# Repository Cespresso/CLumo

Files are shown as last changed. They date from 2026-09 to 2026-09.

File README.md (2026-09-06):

# CLumo

[English] | [日本語 (README.ja.md)](README.ja.md)

CLumo is a palm-sized desk gadget built around an ESP32-C3, an 8x8 LED matrix (MAX7219), and two buttons. It sits on your desk as a tiny companion: a digital pet, a pomodoro timer, a dice roller, or a display you can draw on from your phone.

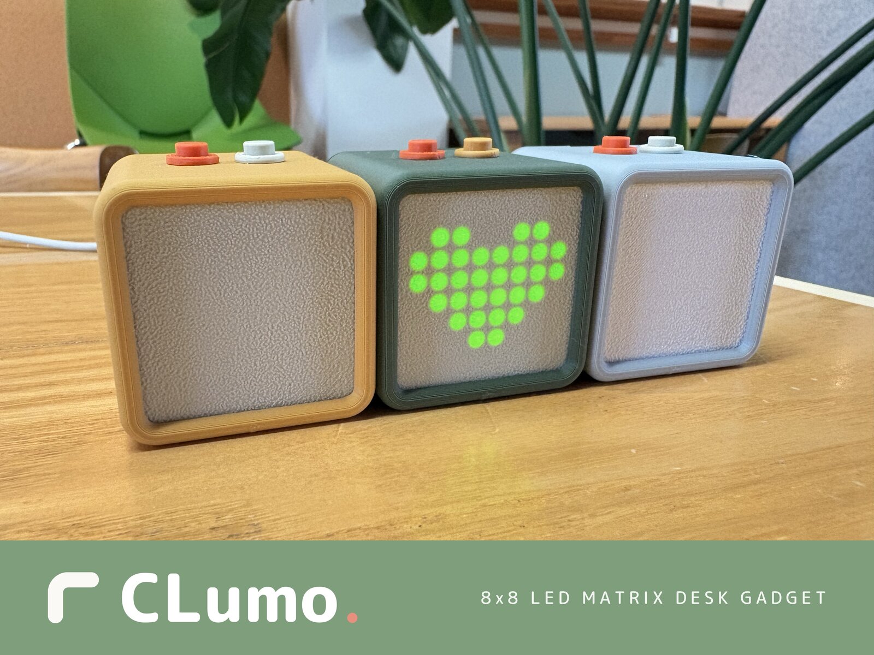
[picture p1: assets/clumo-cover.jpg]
Three CLumo units on a desk in yellow, green, and grey; the green one shows a heart


## Two ways to use it

CLumo ships with two independent firmware variants. Pick one and flash it. You can always switch later.

### 1. Standalone firmware: no app required

Works with just the two buttons; no Bluetooth or phone setup.

- Digital pet: feed it, watch its mood and idle animations
- Pomodoro timer: 25/5 work-break cycles on the LED matrix
- Dice: roll a die with one press

Hold the white button for a second to cycle between modes. The [standalone README](standalone/) lists what each button does in each mode. A running pomodoro and the pet's mood carry across a mode switch, and the mode itself survives a power cycle.

### 2. Companion firmware + Android app

Connects to the CLumo Android app over BLE for richer features.

- Pomodoro: app-configurable work/break cycles shown as a 64-pixel countdown
- Timer: a one-shot countdown from `00:01` to `59:59`, with start, pause, resume, and cancel controls
- My Displays: draw custom 8x8 patterns in the app and send them to the device
- Audio visualizer: the matrix dances to audio streamed from your phone

The [companion README](companion/) covers what the matrix shows before the app connects and what keeps working while the phone is away.

## Quick start

1. Flash the firmware from your browser, no tools to install:
   **https://cespresso.github.io/CLumo/**
   Choose standalone or companion, plug in the device over USB, and click install. Powered by ESP Web Tools; works in Chrome and Edge on desktop, and in Android Chrome via USB-OTG.
2. For the companion firmware, download `clumo.apk` from the [latest GitHub Release](https://github.com/Cespresso/CLumo/releases/latest), install it, and pair with the device using passkey `123456`.

## Repository layout

| Path | Contents |
|---|---|
| [`standalone/`](standalone/) | Standalone firmware (Rust, no BLE): pet / pomodoro / dice |
| [`companion/firmware/`](companion/firmware/) | Companion firmware (Rust + BLE): pomodoro / timer / my displays / visualizer |
| [`companion/android/`](companion/android/) | CLumo Android app (Kotlin, Gradle) |
| [`installer/`](installer/) | Browser-based installer page (ESP Web Tools, served via GitHub Pages) |
| [`hardware/`](hardware/) | Assembly guide, wiring diagram, and 3D-printable enclosure |

## Building from source

Each subproject is self-contained and has its own README with full instructions:

- Firmware ([`standalone/`](standalone/), [`companion/firmware/`](companion/firmware/)): Rust nightly, ESP-IDF v5.2.2, target `riscv32imc-esp-espidf`. Build with `cargo build --release`, flash with `espflash`.
- Android app ([`companion/android/`](companion/android/)): a standard Gradle project. Run `./gradlew assembleDebug` or open it in Android Studio.

## Hardware

- MCU: Seeed XIAO ESP32-C3
- Display: 8x8 LED matrix driven by a MAX7219 (SPI)
- Input: two tactile buttons

The enclosure is five 3D-printed parts. There are no screws or glue: the XIAO snaps into a printed frame, every wire ends in a JST XH connector, and the only soldering is three pin headers. The [assembly guide](hardware/assembly/) walks through the build with photos and includes the parts list and wiring diagram. The 3D model is in [`hardware/models/`](hardware/models/).

## About the AI in this project

CLumo is a one-person project, made with the help of AI tools. The firmware, the Android
app, these READMEs, the installer page, the commit messages and the like were written with
that help: I set the design and the direction, the assistant wrote, and I read it back and
ran it on real CLumo units before every release. The hardware, on the other hand, is
essentially my own hands: designed in a CAD tool, printed, assembled and photographed by me.

## License

[MIT](LICENSE)

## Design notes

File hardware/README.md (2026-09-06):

# Hardware

| Path | Contents |
|---|---|
| [`assembly/`](assembly/) | Step-by-step assembly guide with photos and the wiring diagram ([English](assembly/README.md) / [日本語](assembly/README.ja.md)) |
| [`models/`](models/) | 3D-printable enclosure |

---

| パス | 内容 |
|---|---|
| [`assembly/`](assembly/) | 写真と配線図付きの組み立てガイド（[English](assembly/README.md) / [日本語](assembly/README.ja.md)） |
| [`models/`](models/) | 3D プリント用の外装データ |

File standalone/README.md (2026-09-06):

# CLumo Standalone Firmware

[English] | [日本語 (README.ja.md)](README.ja.md)

Standalone firmware for CLumo. It holds a few simple features that run on nothing but
the two buttons and the LED matrix.

There is no radio, no app, and no pairing: plug in power and everything works with just
the two buttons. Three modes are built in. The current mode is saved to flash, so the
device comes back in the same mode after a power cycle; a running pomodoro and the pet's
mood carry across a mode switch but not across a power cycle.

In the pictures below the left button is orange and the right one is white. Read them as
whatever filament you printed yours with.

## Switching modes

Hold **white** for a second or more. CLumo flashes the icon of the mode it is moving to,
then shows that mode.

| Icon | Mode | What it does |
|:---:|---|---|
| Smiling face | **Pet** | A tiny digital pet that gets hungry over time. Feed it and keep it happy. |
| Hourglass | **Pomodoro** | 25 minutes of work, 5 minutes of break, shown as 64 pixels going out. |
| Five dice pips | **Dice** | Roll a die with one press. |

## Pet

The face is the pet's mood, and the mood follows its hunger: 100 is full, 0 is starving.
It starts at 50 and loses one point every 18 seconds, so an untouched pet goes from
content to sulking in about 3 minutes and to angry in about 12. Feeding adds 20.

| Face | Hunger | Meaning |
|:---:|:---:|---|
| Face with a wide open-mouth smile | 70-100 | Happy. It was fed recently. |
| Face with a small smile | 40-69 | Content. This is where it starts. |
| Face with a downturned mouth | 10-39 | Sad. It wants to be fed. |
| Face with a furrowed brow and downturned mouth | 0-9 | Angry. Feed it now. |

Between moods the pet is never quite still:

| Face | When you see it |
|:---:|---|
| Face with eyes closed | A blink. Happy, content and sad pets blink every couple of seconds; an angry pet just glares. |
| Face with eyes shifted left Face with eyes shifted right | Looking around. Every 5 to 15 seconds it glances left, then right. |

Orange feeds it: hunger goes up by 20 and the pet beams for a moment. White pokes it, and
it scowls for a moment before settling back into its mood.

## Pomodoro

The matrix is the timer. Every phase starts with all 64 pixels lit and they go out one by
one, from the top-left toward the bottom-right, so the lit block shrinking toward the
bottom-right corner is time running out.

| Screen | What it means |
|:---:|---|
| Hourglass | Idle. Nothing is counting. Press orange to start 25 minutes of work. |
| Lower part of the matrix lit | About a third of the way through a phase. Work and break look the same. |
| Bottom rows of the matrix lit | About two thirds of the way through. |
| Every pixel lit | A phase has ended. The whole matrix flashes three times, then the next phase starts on its own: a 5-minute break after work, 25 minutes of work after a break. |

Orange starts the timer when it is idle, pauses it when it is counting, and resumes it
when it is paused; a pause freezes the picture where it is. White resets to idle from any
state.

Both buttons are ignored while the matrix is flashing. Switching to another mode does not
stop the timer: it keeps counting, and you find it where it got to when you come back.

## Dice

The matrix rests on the last roll; a freshly started CLumo shows a five. Press orange and
faces flip past for about a second and a half, slowing down before they land on the result.

| 1 | 2 | 3 | 4 | 5 | 6 |
|:---:|:---:|:---:|:---:|:---:|:---:|
| One pip | Two pips | Three pips | Four pips | Five pips | Six pips |

Orange rolls, and a press while a roll is still spinning is ignored. White has no effect
in this mode.

## Buttons at a glance

| | Orange | White |
|---|---|---|
| **Any mode** | | Hold for a second: next mode |
| **Pet** | Feed | Poke |
| **Pomodoro** | Start / pause / resume | Reset to idle |
| **Dice** | Roll | |

## Build & flash

### Requirements

- Rust nightly with the `rust-src` component. If you use rustup,
  `rust-toolchain.toml` installs it automatically.
- `ldproxy` and `espflash`:

  ```bash
  cargo install ldproxy espflash
  ```

- Python 3.10 or newer
- ESP-IDF v5.2.2

### Flash

Connect the board over USB-C and run:

```bash
cargo run
```

This builds the firmware, flashes it with `espflash`, and opens the serial
monitor.

## Appendix: pin assignments

The board is a Seeed Studio XIAO ESP32C3 and the matrix is a MAX7219.

| GPIO | Connected to | Direction |
|:---:|---|---|
| 8 | Matrix SCLK | Output (SPI) |
| 9 | Matrix CS | Output (SPI) |
| 10 | Matrix MOSI | Output (SPI) |
| 3 | Orange button | Input, internal pull-up (low when pressed) |
| 4 | White button | Input, internal pull-up (low when pressed) |

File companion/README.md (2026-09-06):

# CLumo Companion

[English] | [日本語 (README.ja.md)](README.ja.md)

The firmware and app for using CLumo together with the CLumo Android app. The
device's four functions map one to one onto the app's four functions, and
switching between them, as well as setting durations, happens in the app.

| Directory | Contents |
|---|---|
| [`firmware/`](firmware/) | BLE firmware. The BLE protocol specification lives here too |
| [`android/`](android/) | The CLumo Android app |

Most of what you need to know is already in the app's help pages. This README
therefore concentrates on what the device shows before the app connects, and on
what it does while the phone is away.

In the pictures below the left button is orange and the right one is white. Read
them as whatever filament you printed yours with.

## Getting started

1. Open the [installer page](https://cespresso.github.io/CLumo/), choose the companion firmware, connect the device over USB, and flash.
2. Download `clumo.apk` from the [latest release](https://github.com/Cespresso/CLumo/releases/latest) and install it on a phone running Android 8.0 or newer.
3. Power the device and put it near the phone.
4. Open the app, tap "Find CLumo", and tap the CLumo it finds. Enter passkey `123456` when asked.

From then on, opening the app reconnects on its own.

## When you power it on

The device first shows its connection state, and switches to a function's screen
once the app is connected and ready.

| Screen | What it means |
|:---:|---|
| Thick corner in the top-left | Never paired. A freshly flashed device waits on this screen. Press orange or white and it goes straight to Pomodoro or Timer, usable on its own. |
| Thick corner in the top-left with a dot in the bottom-right | Paired but not connected. Shown for about a second after power-on and right after a disconnect, then the device returns to the function it was last using. |
| The corner-and-dot screen alternating with every pixel off | Connecting. Blinks from the moment the phone connects until the app has finished reading the device's state. |

## The four functions

Switching functions is a matter of picking one in the app. The device's buttons
never change it. The device remembers the last function and comes back to it
after a power cycle. Brightness is a slider in the app, and the device remembers
that too.

| Screen | Function | What it does |
|:---:|---|---|
| Hourglass | **Pomodoro** | Alternates work and break. The durations are set in the app and start out at 25 and 5 minutes. |
| Clock face | **Timer** | A one-shot countdown from 00:01 to 59:59. When time is up it blinks until you do something. |
| Heart | **My Displays** | Shows an 8x8 picture drawn in the app. A heart, a smile, and a star come preloaded. |
| Eight bars of different heights | **Visualizer** | Eight bars move with the audio playing on the phone. Sensitivity is adjusted in the app. |

Pomodoro and Timer show their icon while idle. Once started, the remaining time is
64 pixels: they start fully lit and go out from the top-left toward the
bottom-right.

| Screen | What it means |
|:---:|---|
| Lower part of the matrix lit | About a third of the way through. Work, break, and timer all look the same. A pause freezes the picture where it is. |
| Every pixel lit | The end-of-phase flash. Pomodoro flashes three times and moves to the next phase on its own; Timer keeps blinking until you do something. |

## While the phone is away

Losing the connection does not stop the device. The connection screen shows for
about a second, then the function's screen comes back.

| Function | What the device does on its own |
|---|---|
| **Pomodoro** | Keeps counting. Orange starts, pauses and resumes. White resets. |
| **Timer** | Keeps counting. Orange starts, pauses and resumes, and after completion starts the same duration again. White cancels. |
| **My Displays** | Keeps the last picture sent, even through a power cycle. Switching pictures goes through the app, so the buttons do nothing while it is away. |
| **Visualizer** | The bars fall and go dark once audio stops arriving. The buttons do nothing. |

While connected, orange and white step to the next and previous picture in My
Displays, and raise and lower the sensitivity in Visualizer.

## Permissions

| Permission | When it is asked | What it is for |
|---|---|---|
| Nearby devices (Bluetooth) | On first launch | Finding and connecting to CLumo |
| Microphone | The first time you start the visualizer | Picking up the audio being played |
| Notifications (Android 13 and newer) | The first time you start the visualizer | The notification of the service that keeps the connection |

## Widgets

Two home-screen widgets are included. Both act on the "main CLumo", the one
starred in the device list.

| Widget | Size | What it does |
|---|:---:|---|
| **CLumo controls** | 4x1 | Start, pause, reset and cancel for Pomodoro and Timer. Reconnects when the device is not connected. |
| **CLumo** | 2x2 | Mirrors the device's face. Tapping it opens the app. |

## If something goes wrong

| Symptom | Cause | Fix |
|---|---|---|
| "Find CLumo" finds nothing | The device runs the standalone firmware, which has no Bluetooth | Flash the companion firmware from the installer |
| "This CLumo firmware is not supported" | The companion firmware is out of date | Flash the latest companion firmware from the installer |
| "Connection lost", over and over, on a device that used to work | The device was reflashed and lost its side of the pairing | Forget CLumo in Android's Bluetooth settings, then connect again |

A reflashed device introduces itself as a new one, but the app recognises it as the
same CLumo, so its name, colors, and main-device setting carry over. Enter the passkey
within 30 seconds; after that the device gives up on the pairing and you start over. A device you no longer use
can be removed from the list: hold its card to start tidying and each card's right edge
becomes a remove button. "Remove this device" in the device screen's menu does the same.
The app cannot remove the Android pairing, so forget it in Bluetooth settings separately.
A device removed by mistake comes back through "Find CLumo" with nothing to re-enter.

For anything else, follow the app's dialogs.

## For developers

- BLE protocol specification and firmware build: [`firmware/README.md`](firmware/README.md)
- App build: [`android/README.md`](android/README.md)

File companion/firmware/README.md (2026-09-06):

# CLumo Companion Firmware

Firmware for CLumo, an ESP32-C3 desk gadget with an 8x8 LED matrix (MAX7219)
and two physical buttons. It pairs with the CLumo Android companion app over
BLE; the device's four modes map 1:1 to the app's functions.

This document is the source of truth for the BLE protocol (v3). What the device
shows before the app connects, and what it does while the phone is away, is in
the [companion README](../README.md).

## Modes

| Value | Mode | Description | Buttons |
|---|---|---|---|
| 0 | Pomodoro | Work/break countdown with app-settable durations. The matrix is a 64-pixel progress bar; idle shows an hourglass. | Main: start/pause/resume. Sub: reset. |
| 1 | Timer | One-shot countdown configurable from `00:01` to `59:59`. Idle shows a clock face. At `00:00`, the matrix blinks every 400 ms until operated. | Main: start/pause/resume/restart. Sub: cancel. |
| 2 | Display | Shows the 8-byte bitmap last committed over DISPLAY_FRAME, with DISPLAY_PREVIEW frames drawn on top until they expire. Persisted in NVS across reboots; blank until the first commit arrives. | Reported over BUTTON; the app cycles its saved patterns. |
| 3 | Visualizer | Bar visualizer driven by column heights streamed to the VISUALIZER characteristic. The matrix stays blank until data arrives; bars rise instantly, fall smoothly, and decay to zero when data stops. | Reported over BUTTON; the app steps visualizer sensitivity. |

Modes are selected by the Android companion app through the MODE characteristic;
buttons never change the mode. A mode change immediately shows the selected
mode's normal frame without an icon splash. The current mode is persisted in NVS
and restored on boot. Firmware upgrading from protocol v1 migrates the old
Display value `1` to `2` and Visualizer value `2` to `3`, deriving the result
into the `MODE2` key and leaving the pre-v2 `MODE` and `MODE_SCHEMA` keys
read-only forever. Each NVS setter commits on its own, so migrating in place
across two keys could be interrupted between them; because `1` maps to `2` and
`2` maps to `3`, re-running the migration on its own output would silently turn
Display into Visualizer. Deriving into a separate key makes the migration
idempotent: an interrupted boot recomputes the same value from the same
untouched inputs. Every accepted mode change is pushed to subscribers of the
MODE characteristic.

Buttons register on release after 50 ms of debounce; there is no long press. In
Pomodoro and Timer the firmware acts on the press itself, so those modes stay
usable while disconnected. In Display and Visualizer the firmware only notifies
BUTTON, so those presses do nothing while disconnected.

All mode handlers live for the process lifetime. Pomodoro and Timer continue
counting while another mode is visible and resume from the same state when selected
again. Pomodoro work/break durations, Timer configured duration, brightness, Display
bitmap, and current mode are persisted in NVS. Countdown execution state is not
persisted across reboot; both countdowns boot idle with their stored durations.

While disconnected, the matrix briefly shows the link-loss icon and then returns
to the current mode's standalone frame. A device that has never bonded keeps the
icon up instead, until a phone pairs or a Pomodoro/Timer button press puts it to
standalone use; a device with nothing to reconnect to should not look like it is
running something. The connection icon keeps blinking until a connected client
finishes its encrypted GATT initial sync.

## Build & flash

Requirements:

- Rust **nightly** with the `rust-src` component (see `rust-toolchain.toml`)
- ESP-IDF **v5.2.2** (fetched automatically by `esp-idf-sys`; requires Python >= 3.10)
- Target `riscv32imc-esp-espidf`, linker `ldproxy`, flasher `espflash`

```bash
# Install tooling once
cargo install ldproxy espflash

# Build, flash, and monitor
cargo run
```

## Testing

`lib.rs` exposes the mode-agnostic modules (`countdown`, `display_routing`,
`display_state`, `mode_values`, `settings_values`, `visualizer_values`) so
they can be unit tested on the host, without ESP-IDF. `--target` must override the
crate's default ESP32 target:

```bash
cargo test --lib --target <host-triple>   # e.g. aarch64-apple-darwin, x86_64-unknown-linux-gnu
```

CI runs this on every push and PR (`firmware-ci.yml`). `handlers/`, `mode.rs`, and
`main.rs` depend on ESP-IDF and are not covered by host tests.

## Pairing

- Security: BLE bonding with MITM protection, passkey **123456** (DisplayOnly).
- All readable and writable characteristics require an encrypted (paired) connection.
  BUTTON is notify-only, and NimBLE's auto-generated CCCD is subscribable without
  encryption, so the firmware instead withholds button notifications until a client
  has completed the encrypted initial sync.
- A connected client blocks advertising, so a client that connects but never
  completes that encrypted initial sync (bonds but never reads DEVICE_ID, or isn't
  CLumo's app at all) is force-disconnected after 60s, so a real client isn't
  locked out until power-cycle.

## BLE protocol v3

### State ownership

CLumo (the device) is the sole source of truth for everything it runs or persists;
the app reads and reflects that state rather than assuming it, and reconciles from
a fresh read on every reconnect. Everything the app owns locally never reaches the
device at all. Nothing is owned by both sides: where two representations of the
same fact exist (Display's live preview vs. its committed frame), one is always an
explicit, expiring projection of the other, never an independent second source
(see "Commit, preview and streams" below).

| State | Owner | On reconnect |
|---|---|---|
| Mode | Device (NVS `STATE`) | App re-reads MODE and adopts it as observed; an unexpired (<3s) pending tap is re-sent, not discarded, until the device confirms it |
| Brightness | Device (NVS `STATE`) | Same as Mode |
| Pomodoro/Timer: running state, phase, remaining time | Device only; not persisted, resets to idle on reboot | App re-reads POMODORO/TIMER |
| Pomodoro durations, Timer configured duration | Device (NVS, one namespace per handler) | App re-reads POMODORO/TIMER |
| Display: which 8-byte frame is on the matrix | Device (NVS `DISPLAY`, committed frame only; a live preview is never persisted) | App subscribes to DISPLAY_FRAME and re-reads it; the value is the committed frame, never a live preview |
| Display: pattern names and the app's saved-pattern library | App only; the device has no concept of a pattern, only bytes | Not applicable; the app matches its library against the frame it reads by content |
| Visualizer sensitivity, automatic low-volume boost | App only; a local audio-processing parameter, never sent to the device | Not applicable |
| Device alias, appearance (colors) | App only; cosmetic and local | Not applicable |
| Primary device selection | App only; local | Not applicable |
| Device identity (UUID) | Device (NVS `DEVICE`, generated once on first boot, read-only) | App re-reads DEVICE_ID |

Rule of thumb: if losing power should not lose it, the device owns it and persists
it; if it is purely how the app presents the device (a name, a color, a saved
pattern's name), the app owns it and never sends it.

### Service

| Item | Value |
|---|---|
| Service UUID | `455aa9f0-2999-43de-81b4-54e0de255927` |
| Advertising name | `CLumo-XXXX` where `XXXX` is the uppercase hex of device ID bytes 0 and 1 |

### Characteristics

| Name | UUID | Properties | Payload |
|---|---|---|---|
| MODE | `681285a6-247f-48c6-80ad-68c3dce18586` | READ, WRITE, NOTIFY | 1 byte: mode `0..=3`. Write switches mode; a same-value write is a no-op. Firmware notifies after an accepted mode change. Invalid values are ignored. |
| DISPLAY_PREVIEW | `681285a6-247f-48c6-80ad-68c3dce1858d` | WRITE_NR | 8 bytes: a row bitmap shown at once and never persisted. Ignored outside Display mode. |
| DISPLAY_FRAME | `681285a6-247f-48c6-80ad-68c3dce1858c` | READ, WRITE, NOTIFY | 8 bytes: the committed row bitmap. Write commits in any mode (see below). READ returns the committed frame, never a live preview. Notifies on every commit. |
| VISUALIZER | `681285a6-247f-48c6-80ad-68c3dce1858e` | WRITE_NR | 8 bytes: column heights `0..=8`. Ignored outside Visualizer mode. |
| POMODORO | `681285a6-247f-48c6-80ad-68c3dce18587` | READ, WRITE, NOTIFY | Write: command (below). Read/notify: 6-byte status (below). |
| TIMER | `681285a6-247f-48c6-80ad-68c3dce1858a` | READ, WRITE, NOTIFY | Write: command (below). Read/notify: 5-byte status (below). |
| BRIGHTNESS | `681285a6-247f-48c6-80ad-68c3dce18588` | READ, WRITE, NOTIFY | 1 byte: MAX7219 intensity, clamped to `0..=15`. Firmware echoes the applied value via notify. |
| DEVICE_ID | `681285a6-247f-48c6-80ad-68c3dce18589` | READ | 16 bytes: stable UUIDv4 device identifier, generated on first boot and persisted in NVS. |
| BUTTON | `681285a6-247f-48c6-80ad-68c3dce1858b` | NOTIFY | 2 bytes `[mode, button]`: a button press in a mode the firmware does not handle itself (see below). |

Characteristics are created in the table's order, and ATT handles follow creation
order. The v2 `DISPLAY` characteristic (`…8585`) is gone, and DISPLAY_FRAME's notify
adds a CCCD, so every handle after MODE differs from v2. A client that rediscovers
services finds `…8585` missing and rejects the device (the Android app refreshes its
GATT cache once when a required characteristic is missing, then gives up); a v3 app
does the same on v2 firmware. A bonded client that trusts a stale cache instead
writes at the handles it remembers. Its DISPLAY value handle is now DISPLAY_PREVIEW's
value: volatile, ignored outside Display mode, never persisted. Its POMODORO command
handle is now DISPLAY_FRAME's value, where every v2 command is shorter than 8 bytes
and is rejected with `0x0D` instead of committed. And its TIMER read lands on
VISUALIZER's value, which cannot be read, so its initial sync never completes and it
never streams. Either way no v2 display data can reach NVS, which is the failure v3
exists to remove.

**Add new characteristics at the end of the service, never in the middle.** NimBLE
assigns ATT handles in creation order, so inserting a characteristic ahead of an
existing one shifts that one's handle. A client that already bonded reconnects from
its cached GATT database and keeps using the old handles, so it silently reads the
wrong attribute. This is what broke reconnection entirely when BUTTON was first
added ahead of DEVICE_ID. Appending leaves every existing handle untouched, so clients
upgrading from older firmware keep working; they just do not see the new
characteristic until their cache is refreshed. The companion app forces exactly one
refresh when a characteristic it requires or knows as optional is missing from its
cache, which is how the new features come alive after a firmware upgrade without
re-pairing. v3 broke this rule once, on purpose: the three display characteristics
were placed together after MODE, with the preview stream first so that a v2 client
keeping its cached handles writes its frames into a volatile stream and its short
commands into a characteristic that rejects them, instead of committing into
DISPLAY_FRAME. Three characteristics replace one, so every handle from DISPLAY_FRAME
on was moving regardless. From v3 on, the rule holds again.

### Frame payloads

- **DISPLAY_FRAME and DISPLAY_PREVIEW**: row bitmap. Byte 0 = top row, byte 7 = bottom
  row. Within a byte, bit 7 (MSB) = leftmost column, bit 0 = rightmost column.
- **VISUALIZER**: column heights. Byte 0 = leftmost column, byte 7 = rightmost column.
  Each byte is a height `0..=8` (values above 8 are clamped).

A DISPLAY_FRAME write shorter than 8 bytes is rejected with ATT error `0x0D` (invalid
attribute value length), so the readable committed frame is never replaced by a short
payload. It is also what keeps a stale v2 client's POMODORO commands, which land on
this handle, out of NVS. Short writes to the two streams are logged and dropped; they
have no readable value and write-without-response carries no error. Longer writes are
accepted and only the first 8 bytes are used.

### Commit, preview and streams

A write to DISPLAY_FRAME is a commit: the frame becomes the committed frame in any
mode, is written to NVS when it differs from the previous one, replaces any pending
preview, and is pushed to DISPLAY_FRAME subscribers whether or not it changed, so a
client's pending write is always answered. Display repaints on its next tick if it
is already on the matrix, and shows the frame on entry otherwise. A commit whose NVS
write fails is still notified as accepted: the frame is committed in memory and
shown, and the failure surfaces only as the previous frame returning after a reboot,
with a warning in the firmware log.

A write to DISPLAY_PREVIEW is shown at once while Display is on the matrix and is
never persisted. It expires 5 seconds after the last preview, on a mode change, and
on disconnect, each time restoring the committed frame. Clients keep an edit alive by
re-sending it inside that window.

A write to VISUALIZER moves the bars while Visualizer is on the matrix and is
otherwise dropped.

Nothing rides on MODE besides the mode: there is no announce handshake and no
same-value commit. Of the three display characteristics, only DISPLAY_FRAME
reaches NVS.

### BUTTON notify payload (2 bytes)

| Index | Field | Values |
|---|---|---|
| 0 | `mode` | mode the press happened in: `2` = Display, `3` = Visualizer |
| 1 | `button` | 0 = main, 1 = sub |

Emitted only in Display and Visualizer mode. Pomodoro and Timer presses are
consumed by the firmware and never notified. The firmware holds no state for
these presses: it notifies only after a client has completed the encrypted
initial sync, and a press outside that window is simply lost rather than queued.

Companion apps are expected to treat main as "next / increase" and sub as
"previous / decrease" for whatever that mode presents.

### POMODORO commands (writes)

| Bytes | Command |
|---|---|
| `[0x01]` | Start (from idle) or resume (from paused). No-op while running. |
| `[0x02]` | Pause. No-op unless running. |
| `[0x03]` | Reset: state = idle, phase = work, remaining = work duration. |
| `[0x10, work_min, break_min]` | Set durations in minutes. Both values are clamped to `1..=99` and persisted in NVS. Applied immediately when idle; otherwise the new values take effect from the next reset or phase change. |

Every accepted command results in a status notify, including no-ops as a status
echo. Pomodoro keeps running in the background while another mode is shown, so
Reset is accepted from any mode; Start, Pause, and Set durations are processed
only while the device is in Pomodoro mode (ignored, with a status echo,
otherwise).

### POMODORO status (read value and notify payload, 6 bytes)

| Index | Field | Values |
|---|---|---|
| 0 | `state` | 0 = idle, 1 = running, 2 = paused |
| 1 | `phase` | 0 = work, 1 = break |
| 2..3  | `remaining` | remaining seconds of the current phase, big-endian u16 |
| 4 | `work_min`  | work duration in minutes |
| 5 | `break_min` | break duration in minutes |

The firmware notifies on state or phase changes, once per second while running,
and after every accepted command. When a phase completes, it plays a short
full-screen blink, switches phase, and keeps running.

### TIMER commands (writes)

| Bytes | Command |
|---|---|
| `[0x01]` | Start from idle, resume from paused, or restart the configured duration after completion. No-op while running. |
| `[0x02]` | Pause. No-op unless running. |
| `[0x03]` | Cancel: state = idle and remaining = configured duration. The configured duration is retained. |
| `[0x10, minutes, seconds]` | Set duration while idle. Minutes and seconds must each be `0..=59`, and `00:00` is rejected. While running, paused, or completed, the setting is left unchanged and the current status is echoed. Accepted values are persisted in NVS. |

Every accepted command results in a status notify, including no-ops as a status
echo. The timer keeps running in the background while another mode is shown, so
Cancel is accepted from any mode; Start, Pause, and Set duration are processed
only while the device is in Timer mode (ignored, with a status echo,
otherwise).

### TIMER status (read value and notify payload, 5 bytes)

| Index | Field | Values |
|---|---|---|
| 0 | `state` | 0 = idle, 1 = running, 2 = paused, 3 = completed |
| 1..2  | `remaining` | remaining seconds, big-endian u16 |
| 3 | `minutes` | configured minutes (`0..=59`) |
| 4 | `seconds` | configured seconds (`0..=59`) |

The firmware notifies on state changes, once per second while running, and after
every accepted command. At completion, remaining is `0` and the matrix blinks
on/off every 400 ms until Start/Cancel is received or either button is pressed.

### Countdown LED render rule

Pomodoro and Timer use a 64-pixel countdown progress bar. Companion apps that
mirror the device display must use exactly:

```
lit = ceil(remaining_secs * 64 / total_secs)   // clamped to 0..=64
```

For Pomodoro, `total_secs` is the current phase duration. For Timer, it is the
configured duration. Pixels are indexed row-major from the top-left
(`index = row * 8 + column`, bit 7 = leftmost column); the last `lit` pixel
indices are ON. As time passes, pixels turn off from the top-left toward the
bottom-right. A paused frame remains static.

Idle (state `0`) does not draw the bar. It shows the mode's icon, as row bitmaps
in the DISPLAY_FRAME byte order:

| Mode | Icon | Rows |
|---|---|---|
| Pomodoro | hourglass | `7E 42 24 18 18 24 42 7E` |
| Timer | clock face | `3C 52 91 9D 81 81 42 3C` |

A running or paused countdown with all 64 pixels lit is therefore distinguishable
from idle by the status byte alone, which is what the app's mirror keys on.

## Appendix: pin assignments

The board is a Seeed Studio XIAO ESP32C3 and the matrix is a MAX7219.

| GPIO | Connected to | Direction |
|:---:|---|---|
| 8 | Matrix SCLK | Output (SPI) |
| 9 | Matrix CS | Output (SPI) |
| 10 | Matrix MOSI | Output (SPI) |
| 3 | Main button | Input, internal pull-up (low when pressed) |
| 4 | Sub button | Input, internal pull-up (low when pressed) |

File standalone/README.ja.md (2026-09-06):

# CLumo 単独版ファームウェア

[English (README.md)](README.md) | [日本語]

CLumo の単独版ファームウェアです。ボタン二つとマトリクスLEDだけで機能する簡単な機能が含まれています。

無線もアプリもペアリングもありません。電源をつなげば、ボタン 2 つだけで全部動きます。
モードは 3 つ。現在のモードはフラッシュに保存されるので、電源を入れ直しても同じモードで
立ち上がります。動作中のポモドーロとペットの機嫌はモードを切り替えても続きますが、
電源を切ると消えます。

以下で用いる実機の図は、左が橙ボタン、右が白ボタンにしてますが、適宜利用したフィラメントに応じて読み替えてください。

## モードの切り替え

**白**を 1 秒以上長押しします。移る先のモードのアイコンが一瞬出て、そのモードの画面になります。

| アイコン | モード | できること |
|:---:|---|---|
| にこにこした顔 | **ペット** | 時間とともに腹が減る小さなデジタルペット。餌をやってご機嫌を保ちます。 |
| 砂時計 | **ポモドーロ** | 作業 25 分・休憩 5 分。64 個のドットが消えていくことで残り時間を示します。 |
| サイコロの 5 | **サイコロ** | ボタンひと押しでサイコロを振ります。 |

## ペット

顔がペットの機嫌で、機嫌は空腹度で決まります。100 が満腹、0 が飢え。
50 から始まり、18 秒ごとに 1 減ります。放っておくと 3 分ほどで不機嫌に、12 分ほどで怒ります。
餌をやると 20 増えます。

| 顔 | 空腹度 | 意味 |
|:---:|:---:|---|
| 口を大きく開けて笑う顔 | 70〜100 | ご機嫌。餌をもらったばかり。 |
| 小さく笑う顔 | 40〜69 | 平常。最初はここから。 |
| 口がへの字の顔 | 10〜39 | 不機嫌。餌をほしがっている。 |
| 眉をひそめて口がへの字の顔 | 0〜9 | 怒っている。すぐ餌をやりましょう。 |

機嫌とは別に、ペットはじっとしていません。

| 顔 | いつ出るか |
|:---:|---|
| 目を閉じた顔 | まばたき。ご機嫌・平常・不機嫌のときは数秒おきにまばたきします。怒っているときはにらんだままです。 |
| 目が左に寄った顔 目が右に寄った顔 | よそ見。5〜15 秒おきに左、右と目をやります。 |

橙で餌をやると空腹度が 20 増え、ペットが一瞬にっこりします。白でつつくと一瞬むっとして、
元の機嫌に戻ります。

## ポモドーロ

マトリクスそのものがタイマーです。どのフェーズも 64 個全部が点いた状態から始まり、
左上から右下へ向かって 1 つずつ消えていきます。点いている塊が右下の角へ縮んでいくのが、
残り時間です。

| 画面 | 意味 |
|:---:|---|
| 砂時計 | 待機中。何も動いていません。橙を押すと 25 分の作業が始まります。 |
| マトリクスの下側が点灯 | フェーズの 3 分の 1 ほどが過ぎたところ。作業も休憩も同じ見え方です。 |
| マトリクスの下 2 段強が点灯 | 3 分の 2 ほどが過ぎたところ。 |
| 全ドット点灯 | フェーズ終了。全体が 3 回点滅し、次のフェーズが自動で始まります。作業のあとは 5 分の休憩、休憩のあとは 25 分の作業です。 |

橙は待機中なら開始、カウント中なら一時停止、停止中なら再開です。一時停止すると絵はその場で
止まります。白はどの状態からでも待機中に戻します。

点滅している間はどちらのボタンも受け付けません。他のモードに切り替えてもタイマーは止まりません。
戻ってくると、進んだところから続いています。

## サイコロ

マトリクスには最後に出た目が残ります。起動直後は 5 です。橙を押すと 1.5 秒ほど目がめくれ、
だんだん遅くなって結果に止まります。

| 1 | 2 | 3 | 4 | 5 | 6 |
|:---:|:---:|:---:|:---:|:---:|:---:|
| サイコロの 1 の目 | サイコロの 2 の目 | サイコロの 3 の目 | サイコロの 4 の目 | サイコロの 5 の目 | サイコロの 6 の目 |

橙で振ります。回転中に押しても受け付けません。白はこのモードでは何もしません。

## ボタン早見表

| | 橙 | 白 |
|---|---|---|
| **全モード共通** | | 1 秒長押し: 次のモードへ |
| **ペット** | 餌をやる | つつく |
| **ポモドーロ** | 開始 / 一時停止 / 再開 | 待機中に戻す |
| **サイコロ** | 振る | |

## ビルドと書き込み

### 必要なもの

- `rust-src` コンポーネント付きの Rust nightly。rustup を使っていれば
  `rust-toolchain.toml` が自動で入れます。
- `ldproxy` と `espflash`:

  ```bash
  cargo install ldproxy espflash
  ```

- Python 3.10 以上
- ESP-IDF v5.2.2

### 書き込み

ボードを USB-C でつないで:

```bash
cargo run
```

ビルドして `espflash` で書き込み、シリアルモニタを開きます。

## 付録: ピン配置

ボードは Seeed Studio XIAO ESP32C3、LED マトリクスは MAX7219 です。

| GPIO | つながる先 | 向き |
|:---:|---|---|
| 8 | マトリクス SCLK | 出力（SPI） |
| 9 | マトリクス CS | 出力（SPI） |
| 10 | マトリクス MOSI | 出力（SPI） |
| 3 | 橙ボタン | 入力、内部プルアップ（押すと Low） |
| 4 | 白ボタン | 入力、内部プルアップ（押すと Low） |

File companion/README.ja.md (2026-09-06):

# CLumo アプリ協調版

[English (README.md)](README.md) | [日本語]

CLumo を Android アプリ「CLumo」と組み合わせて使うための、ファームウェアとアプリのセットです。
本体の 4 つの機能はアプリの 4 つの機能と一対一で対応していて、機能の切り替えや時間の設定はアプリから行います。

| ディレクトリ | 内容 |
|---|---|
| [`firmware/`](firmware/) | BLE 対応ファームウェア。BLE プロトコルの仕様もここにあります |
| [`android/`](android/) | Android アプリ「CLumo」 |

使い方の説明の多くは、アプリの中のヘルプにある程度書いてあります。
そのため、この README では、アプリが開く前の本体の表示と、スマホが手元にないときの本体の動きを中心にまとめています。

以下で用いる実機の図は、左が橙ボタン、右が白ボタンにしてますが、適宜利用したフィラメントに応じて読み替えてください。

## はじめる

1. [インストーラページ](https://cespresso.github.io/CLumo/)で「アプリ協調版」を選び、本体を USB でつないで書き込みます。
2. [最新の Release](https://github.com/Cespresso/CLumo/releases/latest) から `clumo.apk` をダウンロードして、Android 8.0 以上のスマホにインストールします。
3. 本体の電源を入れて、スマホの近くに置きます。
4. アプリを開いて「CLumo を探す」を押し、見つかった CLumo をタップします。求められたらパスキー `123456` を入力します。

次からは、アプリを開くだけで自動的に再接続します。

## 電源を入れると

本体はまず接続の状態を表示し、アプリがつながって準備を終えると、それぞれの機能の画面に
切り替わります。

| 画面 | 意味 |
|:---:|---|
| 左上に太い角 | まだ一度もペアリングしていません。書き込み直後の本体はこの画面のまま待ちます。橙か白を押せば、その場でポモドーロやタイマーを本体だけで使えます。 |
| 左上に太い角、右下に点 | ペアリング済みですが、つながっていません。起動直後と切断された直後に 1 秒ほど表示され、そのあと最後に使っていた機能の画面に戻ります。 |
| 角と点の画面と、全ドット消灯の画面が交互に | 接続中。スマホがつながってから、アプリが本体の状態を読み終えるまで点滅します。 |

## 4 つの機能

機能の切り替えはアプリで選ぶだけで、本体のボタンでは変わりません。本体は最後に選んだ機能を
覚えていて、電源を入れ直してもその機能で立ち上がります。明るさもアプリのスライダーで変え、
本体が覚えます。

| 画面 | 機能 | できること |
|:---:|---|---|
| 砂時計 | **ポモドーロ** | 作業と休憩を交互に繰り返します。分数はアプリで設定でき、最初は作業 25 分・休憩 5 分です。 |
| 時計の文字盤 | **タイマー** | 00:01 から 59:59 までの一回きりのカウントダウン。時間が来ると操作されるまで点滅します。 |
| ハート | **マイ表示** | アプリで描いた 8×8 の絵を本体に表示します。最初からハート・スマイル・ほしが入っています。 |
| 高さの違う 8 本のバー | **ビジュアライザ** | スマホで再生中の音に合わせて 8 本のバーが動きます。感度はアプリで調整します。 |

ポモドーロとタイマーは、待機中は上のアイコンを出し、始めると残り時間を 64 個のドットで
示します。全部点いた状態から始まり、左上から右下へ向かって消えていきます。

| 画面 | 意味 |
|:---:|---|
| マトリクスの下側が点灯 | 3 分の 1 ほど過ぎたところ。作業、休憩、タイマーのどれも同じ見え方です。一時停止すると絵はその場で止まります。 |
| 全ドット点灯 | 終了の点滅。ポモドーロは 3 回点滅して次のフェーズへ自動で進み、タイマーは操作されるまで点滅し続けます。 |

## スマホが離れているとき

接続が切れても本体は止まりません。切れた直後に接続の画面が 1 秒ほど出て、そのあと機能の
画面に戻ります。

| 機能 | 本体だけでできること |
|---|---|
| **ポモドーロ** | 動き続けます。橙で開始・一時停止・再開、白でリセット。 |
| **タイマー** | 動き続けます。橙で開始・一時停止・再開、終了後の橙は同じ時間でもう一度。白でキャンセル。 |
| **マイ表示** | 最後に送った絵がそのまま残り、電源を切っても消えません。絵の切り替えはアプリを通すので、離れている間はボタンを押しても何も起きません。 |
| **ビジュアライザ** | 音が届かなくなるとバーが下がって消えます。ボタンは何もしません。 |

つながっているときは、マイ表示では橙で次の絵、白で前の絵に切り替わり、ビジュアライザでは
橙で感度が上がり、白で下がります。

## 権限

| 権限 | 尋ねるとき | 使いみち |
|---|---|---|
| 付近のデバイス（Bluetooth） | 初回起動時 | CLumo を探して接続する |
| マイク | ビジュアライザを初めて開始するとき | 再生中の音を拾う |
| 通知（Android 13 以上） | ビジュアライザを初めて開始するとき | 接続を保つサービスの通知を出す |

## ウィジェット

ホーム画面に置けるウィジェットが 2 種類あります。どちらも、一覧で ☆ を付けた
「メインの CLumo」に対して動きます。

| ウィジェット | 大きさ | できること |
|---|:---:|---|
| **CLumo 操作** | 4×1 | ポモドーロとタイマーの開始・一時停止・リセット・キャンセル。つながっていなければ再接続。 |
| **CLumo** | 2×2 | 本体の顔をそのまま映します。タップするとアプリが開きます。 |

## つまずいたら

| 症状 | 原因 | 対処 |
|---|---|---|
| 「CLumo を探す」で見つからない | 単独版ファームウェアが入っている。単独版は Bluetooth を持ちません | インストーラで協調版を書き込む |
| 「このCLumoのファームウェアには対応していません」 | 協調版ファームウェアが古い | インストーラで最新の協調版を書き込む |
| 以前つながっていた本体に「接続が切れました」が続く | 本体を書き直して、本体側のペアリングが消えている | Android の Bluetooth 設定で CLumo を削除してから、もう一度接続する |

書き直した本体は新しい本体として名乗りますが、アプリは同じ本体だと分かるので、名前・色・
メイン設定はそのまま引き継がれます。パスキーの入力は 30 秒以内に済ませてください。
間に合わないと本体側が認証を打ち切り、ペアリングからやり直しになります。使わなくなった本体は一覧から消せます。カードを長押しすると整理モードになり、
各カードの右端が削除ボタンに変わります。デバイス画面のメニューの「このデバイスを削除」も
同じ動作です。Android 側のペアリングはアプリからは消せないので、Bluetooth 設定で別途
削除してください。消したあとで戻したくなったら、「CLumo を探す」で見つけて接続すれば
元どおりです。

それ以外はアプリのダイアログの案内に従ってください。

## 開発者向け

- BLE プロトコルの仕様とファームウェアのビルド: [`firmware/README.md`](firmware/README.md)（英語）
- アプリのビルド: [`android/README.ja.md`](android/README.ja.md)

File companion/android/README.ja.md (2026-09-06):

# CLumo Android アプリ

[English (README.md)](README.md) | [日本語]

アプリ協調版ファームウェア用の Android アプリです。何ができるか、本体がどう動くかは
[協調版の README](../README.ja.md) にまとめてあります。

## 必要なもの

- Android 8.0 以上で Bluetooth Low Energy を備えたスマホ
- JDK 17。Android Studio に同梱されています。なければ JDK だけ入れれば、
  残りは Gradle ラッパーが取ってきます。

## ビルド

```bash
./gradlew assembleDebug
```

APK は `app/build/outputs/apk/debug/` にできます。デバッグビルドはパッケージ名が
別なので、リリース版と置き換わらず並んでインストールされます。

## リリースビルド

リリースビルドは、`CLUMO_KEYSTORE_PATH`、`CLUMO_KEYSTORE_PASSWORD`、`CLUMO_KEY_ALIAS`、
`CLUMO_KEY_PASSWORD` の 4 つの環境変数で指す keystore で署名します。どれかが欠けていると、
デバッグ鍵で代用せずにビルドが失敗します。署名済みの APK は
[GitHub Releases](https://github.com/Cespresso/CLumo/releases/latest) に `clumo.apk` として
置いています。

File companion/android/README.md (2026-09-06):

# CLumo Android App

[English] | [日本語 (README.ja.md)](README.ja.md)

The Android app for the companion firmware. What it does and how the device
behaves alongside it is covered in the [companion README](../README.md).

## Requirements

- A phone running Android 8.0 or newer with Bluetooth Low Energy
- JDK 17. Android Studio brings one; otherwise install one and let the Gradle
  wrapper fetch everything else.

## Build

```bash
./gradlew assembleDebug
```

The APK lands in `app/build/outputs/apk/debug/`. A debug build has its own
package name, so it installs next to a release build instead of replacing it.

## Release builds

Release builds are signed with a keystore named by four environment variables:
`CLUMO_KEYSTORE_PATH`, `CLUMO_KEYSTORE_PASSWORD`, `CLUMO_KEY_ALIAS`, and
`CLUMO_KEY_PASSWORD`. A release task fails when any of them is missing rather
than falling back to the debug key. Signed release APKs are published on
[GitHub Releases](https://github.com/Cespresso/CLumo/releases/latest) as
`clumo.apk`.

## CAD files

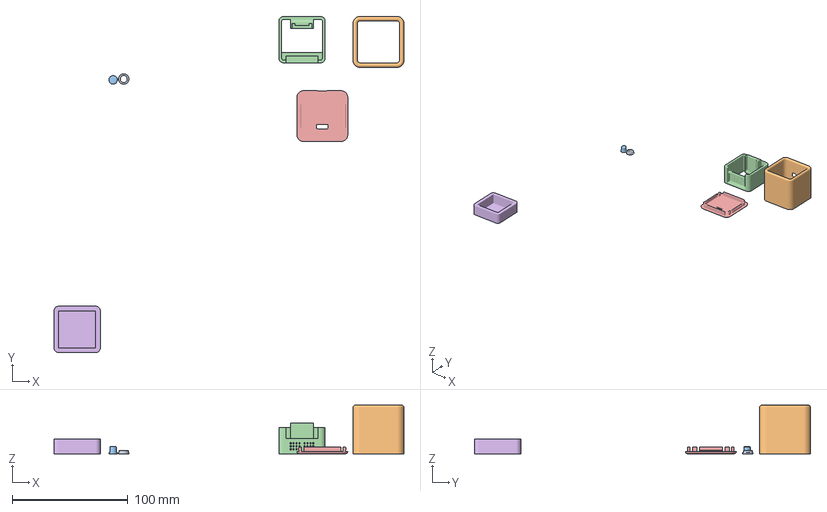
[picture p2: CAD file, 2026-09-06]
hardware/models/clumo.3mf
302.0 x 290.0 x 42.0 mm
button1
enclosure1
button2
chassis
enclosure2
surface

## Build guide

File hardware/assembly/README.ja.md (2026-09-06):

# CLumo 組み立てガイド

[English](README.md) | 日本語

必要な作業として大きなものは、はんだ付け（ピンヘッダ程度）と JST XH の圧着です。配線の結び方は手順 3 の配線図にまとめてあります。
※ JST XHコネクタを使わずに全て半田付けでも組み立てすることは一応可能ですが、難易度や取り回しの問題から非推奨です。このページではコネクタありで進めます。

## 用意するもの

図 1 が部品を並べたところです。JST コネクタ類は写真に写っている数より多く必要なので、数は下の表で確認してください。

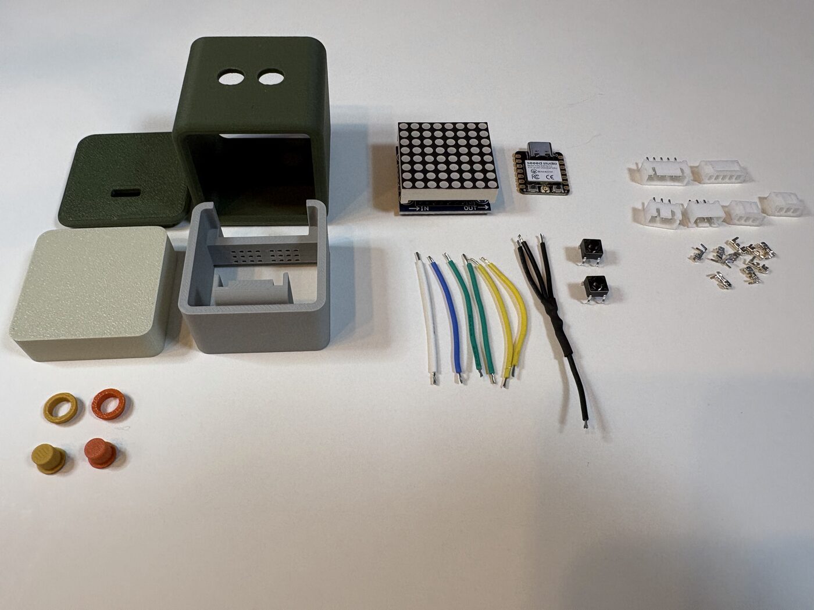
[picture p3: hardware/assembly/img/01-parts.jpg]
部品一覧。造形物、XIAO、マトリクスモジュール、電線、タクトスイッチ、JST 部品


図 1: 造形物と電子部品を並べた状態です。JST 部品は一部しか写っていません。

### 電子部品

| 部品 | 数 | 備考 |
|---|---|---|
| Seeed XIAO ESP32-C3 | 1 | |
| MAX7219 8x8 LED マトリクスモジュール | 1 | 基板が 32 mm 角の一般的なもの |
| タクトスイッチ 6x6 mm | 2 | 4 本足のもの |
| 熱収縮チューブ | 少々 | GND のスプライスを覆う分 |

### JST XH 2.54 mm

互換品のキットで揃います。基板側ヘッダはすべてストレートです。

| 部品 | 数 | 用途 |
|---|---|---|
| 5 ピン 基板ヘッダ | 2 | XIAO 左列 / マトリクス IN |
| 2 ピン 基板ヘッダ | 1 | XIAO 右列 |
| 5 ピン ハウジング | 2 | XIAO 左列側 / マトリクス側 |
| 2 ピン ハウジング | 1 | XIAO 右列側 |
| 3 ピン ハウジング | 2 | ボタン。両端の 2 極だけ使い、真ん中は空けます |
| 圧着コンタクト | 16 | |

### 電線

長さはどれも 5 cm 前後。
自分で作った感じこれより短いと取り扱いが難しく、いくらか長くはできますが、逆に長すぎるとケースに収まらなくなるので注意してください。

| 種類 | 本数 | つなぐ区間 |
|---|---|---|
| 色線 | 4 | XIAO と マトリクスの間（3V3 / D10 / D9 / D8） |
| 色線 | 2 | XIAO と各ボタンの間（D1 / D2） |
| 黒 | 4 | GND。XIAO から 1 本、途中で 3 本に分岐してマトリクスと両ボタンへ |

### 造形物

図 2 の 5 種類です。ボタンは軸受とキャップの 2 部品で、色を変えて刷るとアクセントになります。3D データは [`clumo.3mf`](../models/clumo.3mf) です。

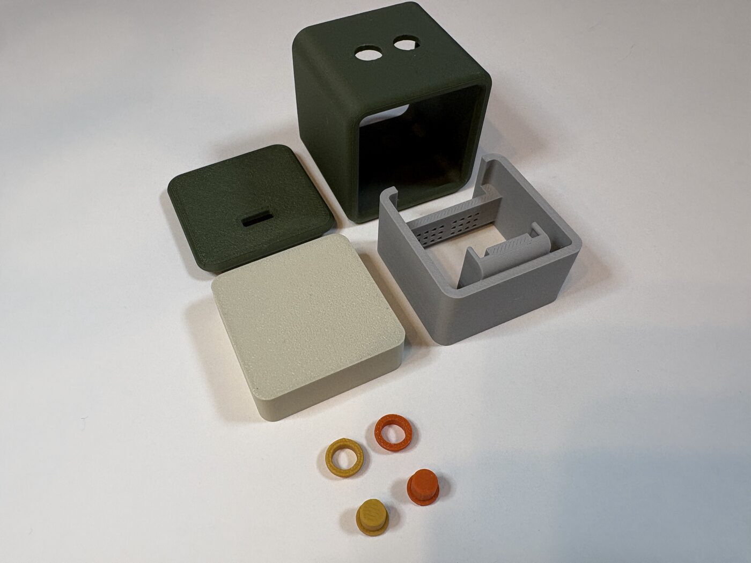
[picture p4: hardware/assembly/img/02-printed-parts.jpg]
造形物。外装シェル、背面パネル、白いトレイ、灰色の骨格、ボタンの軸受とキャップ


図 2: 造形物は外装シェル、背面パネル、トレイ、骨格、ボタン 2 組です。

| 部品 | 写真の色 | 役割 |
|---|---|---|
| 外装シェル | 濃緑 | 天面にボタン用の丸穴 2 つ、前後に大きな穴 |
| 背面パネル | 濃緑 | 背面の口を塞ぐ。細長い穴が USB-C の差し込み口 |
| トレイ | 白 | マトリクスをはめる浅い箱。底がそのまま拡散板になります |
| 骨格 | 灰色 | XIAO とスイッチを載せる。配線はすべてここで行います |
| ボタン軸受 | 黄 / 橙 | 外装の丸穴にはめるリング |
| ボタンキャップ | 黄 / 橙 | 押す部分 |

### 工具

はんだごて、JST XH 用の圧着工具、ニッパー、ワイヤーストリッパー。

## 全体の流れ

1. マトリクスにヘッダを付けてトレイに入れる
2. XIAO にヘッダを付ける
3. ハーネスを作る
4. 骨格にスイッチを入れる
5. XIAO を骨格にはめる
6. 骨格の中でコネクタをつなぐ
7. トレイと骨格を合わせる
8. 外装に入れる
9. ボタンを付ける
10. 背面パネルをはめる
11. ファームウェアを書き込む

## 1. マトリクスにヘッダを付けてトレイに入れる

モジュールには同じ形のヘッダ列が 2 つあります。5 ピンのヘッダをはんだ付けするのは、シルクが VCC / GND / **DIN** / CS / CLK の側です（図 3）。反対側は DOUT で、2 枚目をつなぐための出力です。こちらに付けると何も表示されません。

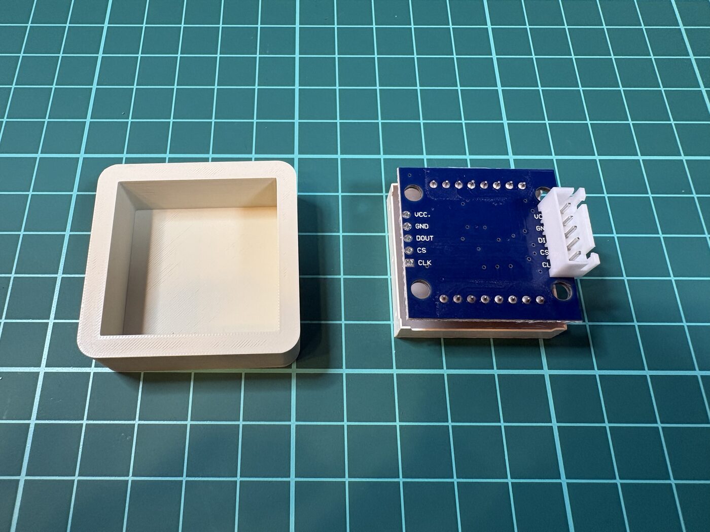
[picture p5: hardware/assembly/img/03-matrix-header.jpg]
マトリクスモジュールの裏面と白いトレイ。DIN 側に 5 ピンヘッダが付いている


図 3: ヘッダは DIN と書かれた側に付けます。左の列が DOUT、右の列が DIN です。

ヘッダを付けたら、LED の面を下にしてトレイに落とし込みます。基板の裏が上を向き、コネクタがトレイの縁から出ている状態になれば正しく入っています。

## 2. XIAO にヘッダを付ける

XIAO のパッドはどちらの列も端から使うわけではないので、位置を確かめてからはんだ付けします。図 4 は裏面（シルクにピン名が書かれている面）から見たものです。

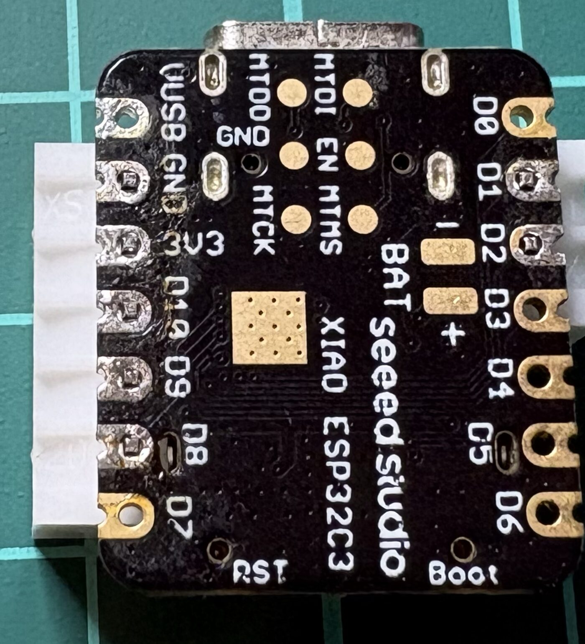
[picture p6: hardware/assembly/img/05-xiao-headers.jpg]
XIAO ESP32-C3 の裏面。左列の GND から D8 まで 5 パッド、右列の D1 と D2 にはんだが乗っている


図 4: 左列は GND から D8 までの 5 パッド、右列は D1 と D2 の 2 パッドにヘッダを付けます。

| 列 | ヘッダ | パッド | つなぐ先 |
|---|---|---|---|
| 5V 側の列 | 5 ピン | GND / 3V3 / D10 / D9 / D8 | マトリクス(※GNDのみボタン共用) |
| D0 側の列 | 2 ピン | D1 / D2 | ボタン |

## 3. ハーネスを作る

結線は図 5 のとおりです。XIAO の 5 ピンとマトリクスの 5 ピンは 4 本の色線で直結し、GND だけは XIAO から出た 1 本を途中で 3 本に分岐させて、マトリクスと両方のボタンに配ります。分岐は熱収縮チューブで覆います。

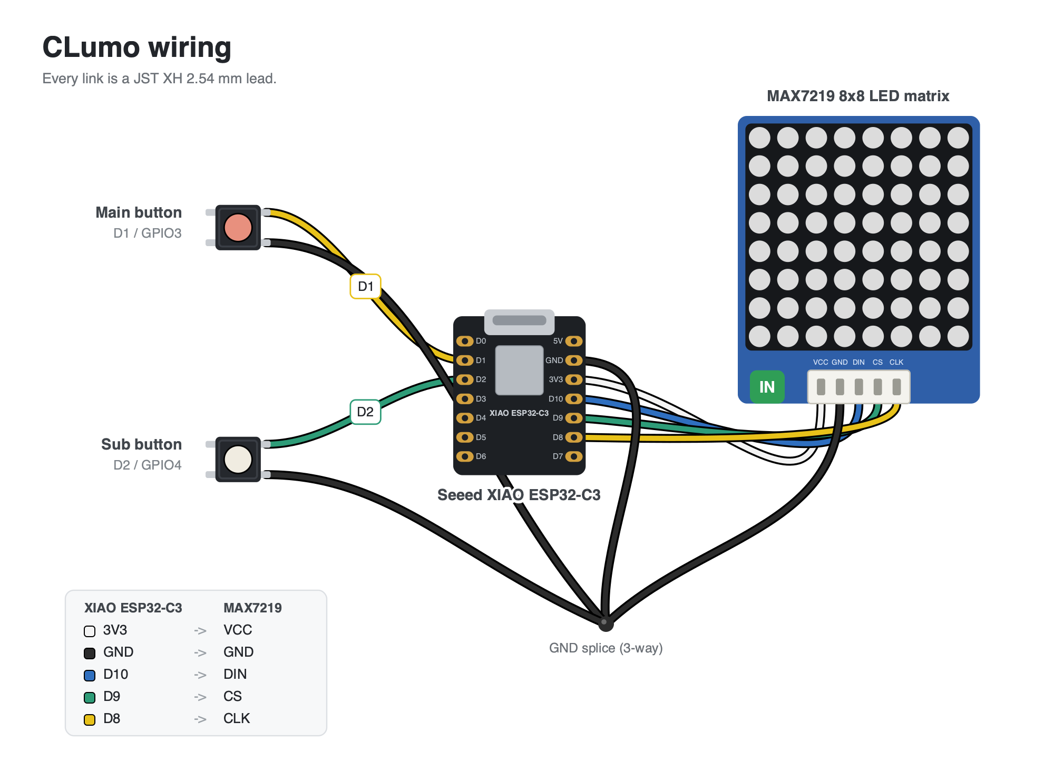
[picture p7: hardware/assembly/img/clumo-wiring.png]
配線図。XIAO の GND / 3V3 / D10 / D9 / D8 をマトリクスの VCC / GND / DIN / CS / CLK に、D1 / D2 を 2 つのボタンにつなぐ


図 5: 結線は 5 本のマトリクス側と 2 本のボタン側で、GND だけが 1 本から 3 つに分かれます。

ボタン側は 3 ピンのハウジングを使いますが、圧着するのは両端の 2 極だけで、真ん中は空けます。XH の 2.54 mm ピッチ 2 つ分が、タクトスイッチの足の間隔にちょうど合うためです。各ボタンのハウジングには、XIAO の D1 または D2 から来る色線 1 本と、分岐した GND 1 本が入ります。できあがりは図 6 のようになります。

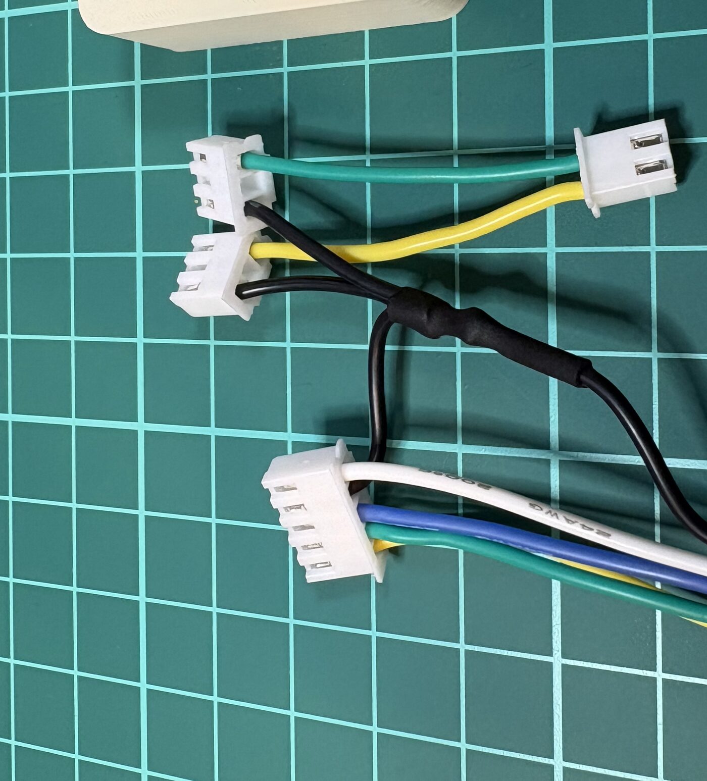
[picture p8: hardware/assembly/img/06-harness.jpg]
完成したハーネス。5 ピン 2 個、2 ピン 1 個、3 ピン 2 個のハウジングと、熱収縮チューブで覆った GND の分岐


図 6: ハーネスは 5 つのハウジングで構成され、黒の GND だけが途中で 3 本に分かれます。

## 4. 骨格にスイッチを入れる

骨格の天板に、スイッチがはまる角穴が 2 つあります。そこに外側からタクトスイッチを押し込みます（図 7）。

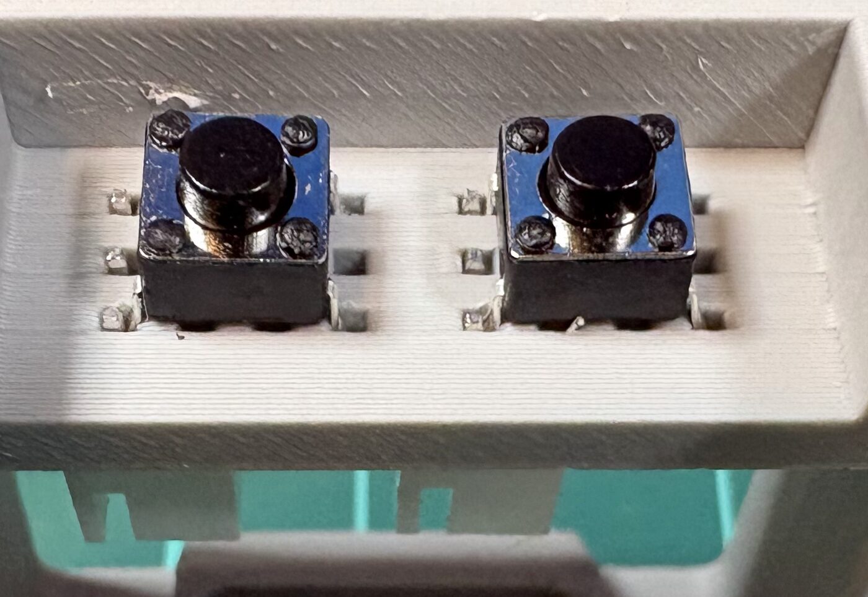
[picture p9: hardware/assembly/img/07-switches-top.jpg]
骨格の天板に 2 つのタクトスイッチがはまり、足が両脇の 3 連スリットに収まっている


図 7: スイッチを外側から押し込むと、足が両脇のスリットに入ります。

次に、ハーネスの 3 ピンハウジングを骨格の内側から同じスリットに差し込みます。ハウジングの圧着コンタクトがスイッチの足に当たり、骨格の穴の締まりだけで固定されます（図 8）。はんだは使いません。

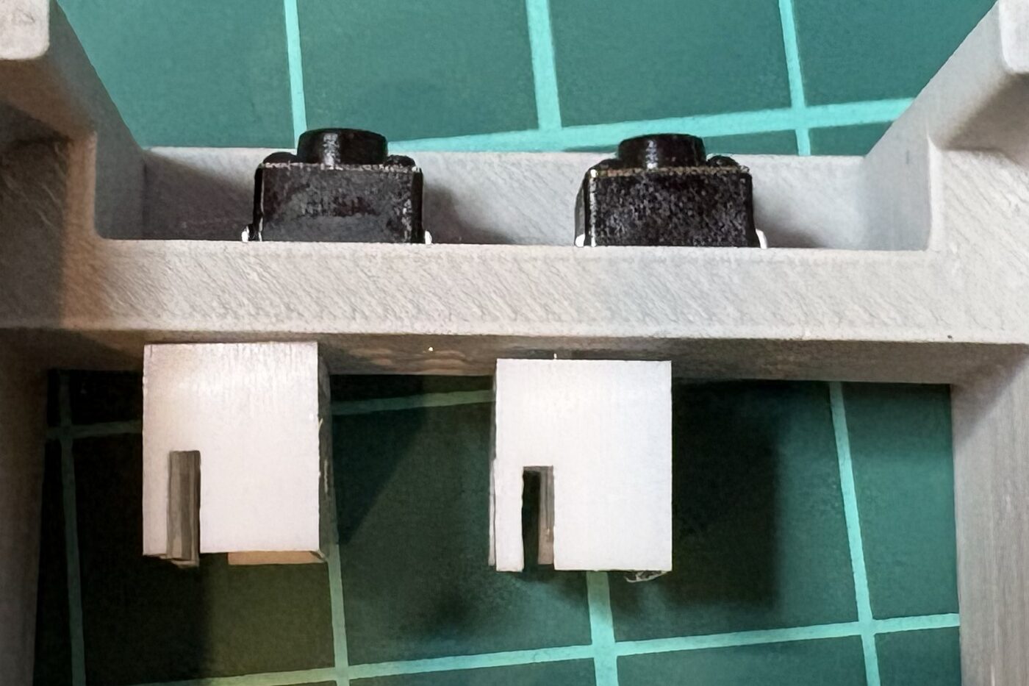
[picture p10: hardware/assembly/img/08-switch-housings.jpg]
骨格を裏から見た様子。2 つの 3 ピンハウジングが下から差し込まれている


図 8: 3 ピンハウジングは下から差し込み、骨格の穴の締まりで留まります。

差し込む向きは、コンタクトが入っている両端の極がスイッチの足に来るようにします。真ん中の空いた極が中央のスリットに合えば正しい向きです。

差し込んだコンタクトはスリットから頭を出すので、そこをスイッチの足にはんだ付けしてもかまいません。ただしすぐ横が PLA で、溶かさずに付けるのは難しいです。圧着だけで十分に動くので、やるかどうかは自己判断でお願いします。

## 5. XIAO を骨格にはめる

骨格の中に XIAO を受ける爪付きのクレードルがあります。USB-C を背面（骨格の開いている側）に向け、シールド缶のある面を上にして押し込むと、少し硬いですがスナップフィットで留まります（図 9）。

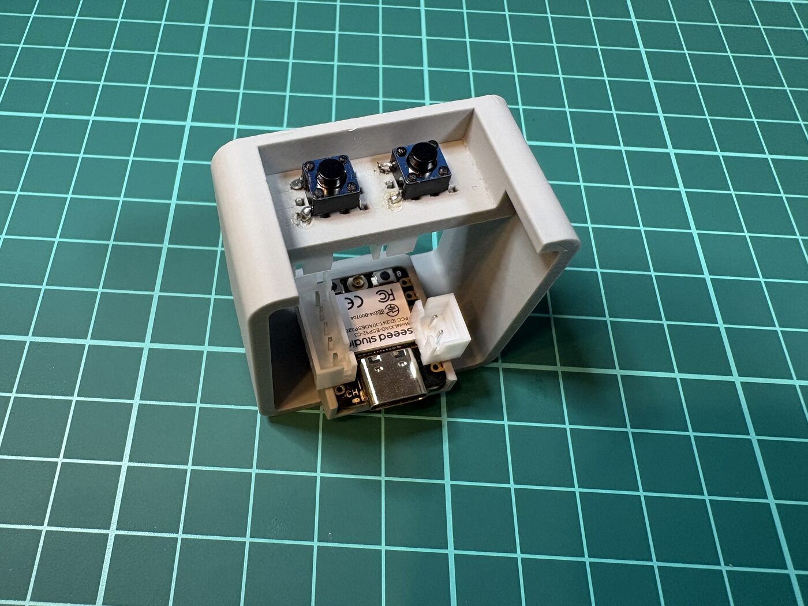
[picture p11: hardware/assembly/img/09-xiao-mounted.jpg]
骨格に XIAO がはまり、USB-C が手前を向き、2 つのヘッダが上を向いている


図 9: XIAO は USB-C を背面に向けてスナップフィットで留めます。

向きはこれ 1 通りです。逆にすると背面パネルの穴に USB-C が来ません。

## 6. 骨格の中でコネクタをつなぐ

骨格の中は狭く、天板と XIAO の隙間で作業することになります。

> XIAO の 5 ピンコネクタとボタンのハウジングは位置が重なりコツが入ります。他にも方法があるかもですが、自分は以下の手法で入れてます。
> 1. まず両方のボタンの 3 ピンハウジングを差し込む（手順 4）
> 2. XIAO の 2 ピンに D1 / D2 のハウジングを差す
> 3. 最後に XIAO の 5 ピンを、USB-C 側から少しスライドさせるように差す

つなぎ終わると図 10 のようになります。マトリクスへ行く 5 本は上へ抜いたままにしておきます。

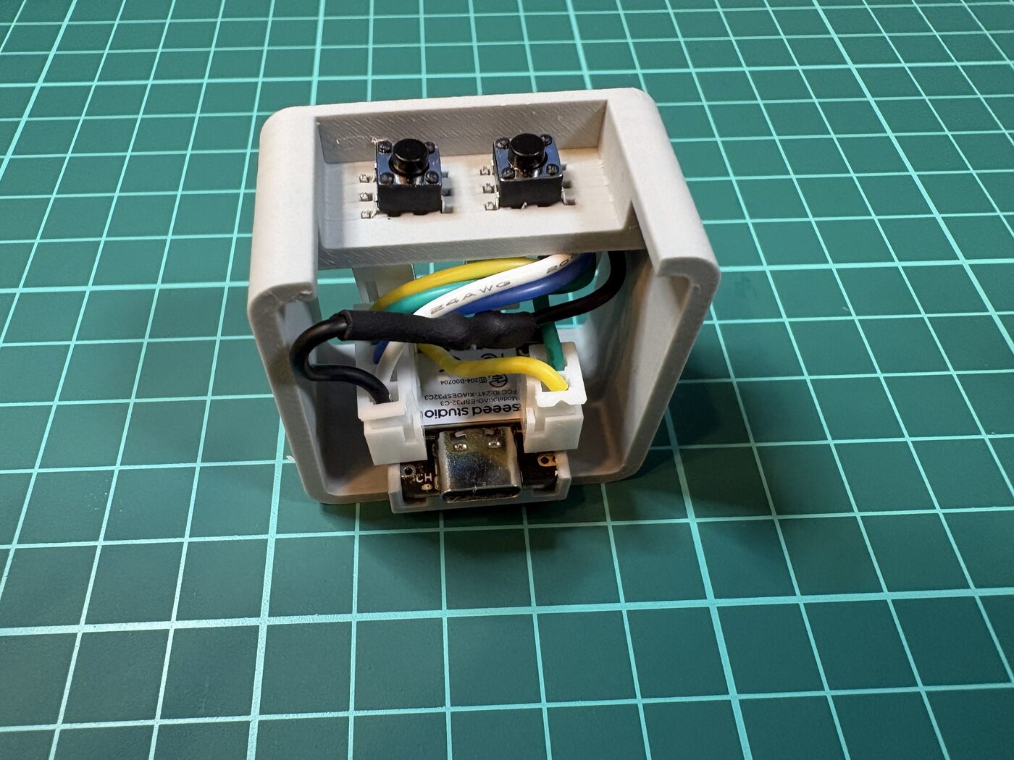
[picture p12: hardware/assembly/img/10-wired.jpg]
骨格の中で XIAO の 2 つのコネクタと両ボタンのハウジングが接続され、マトリクス用のケーブルが上に出ている


図 10: マトリクスへ行くケーブル以外がすべてつながった状態です。

## 7. トレイと骨格を合わせる

マトリクスの 5 ピンコネクタにハーネスを差し、トレイと骨格を向き合わせて重ねます（図 11）。

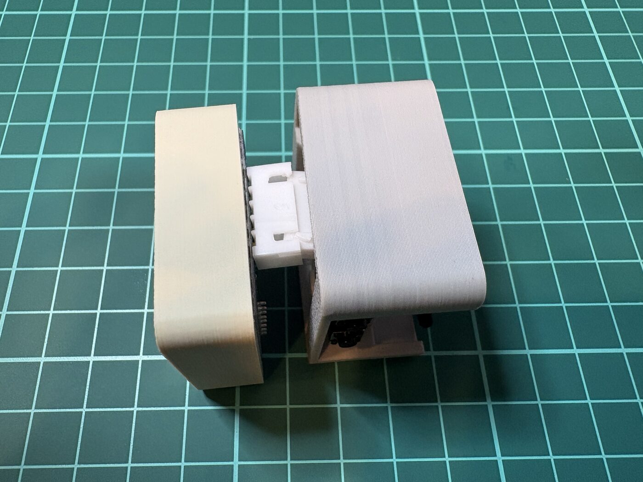
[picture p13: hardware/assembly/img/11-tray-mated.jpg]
白いトレイと灰色の骨格が JST コネクタでつながり、横に並んでいる


図 11: トレイと骨格はコネクタ 1 つでつながります。

## 8. 外装に入れる

外装シェルには口が 2 つあります。正面の少し小さい口が LED の窓、背面の広い口が中身を入れる側です。次の 4 つを合わせて、広い口から押し込みます（図 12）。

| 合わせるもの | 位置 |
|---|---|
| トレイ（白） | 正面の小さい口 |
| 骨格（灰色） | 背面の広い口 |
| 丸穴 2 つの面 | 上 |
| USB-C | 下 |

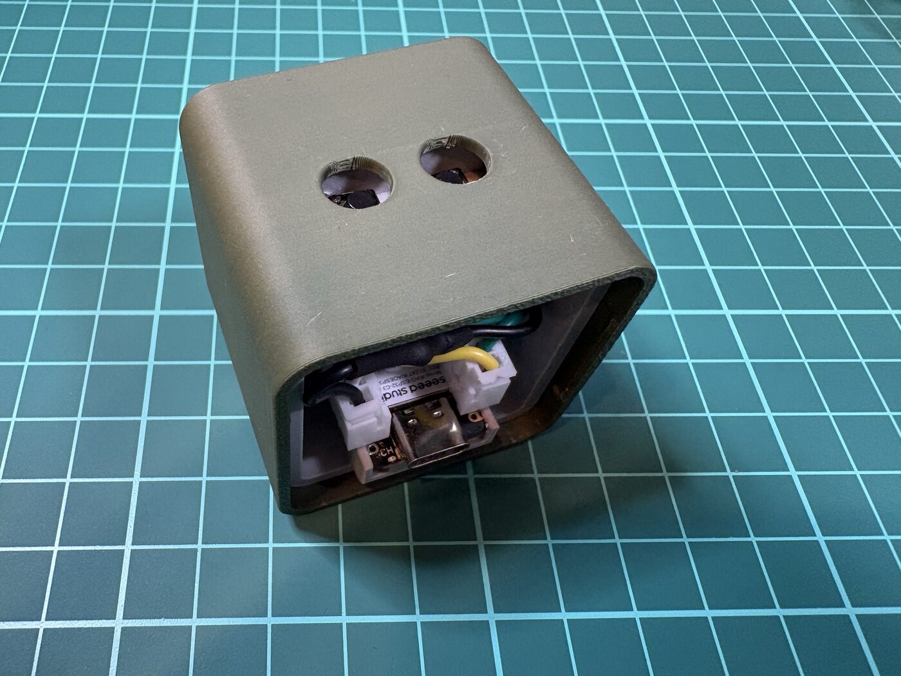
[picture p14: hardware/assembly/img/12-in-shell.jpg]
外装シェルに中身が入り、天面の丸穴からスイッチが、背面から XIAO の USB-C が見えている


図 12: 正しく入ると、天面の丸穴からスイッチが、背面の下側から USB-C が見えます。

## 9. ボタンを付ける

ボタンは外側から付けます。まずキャップを天面の丸穴に入れ（図 13）、そのあと軸受のリングをキャップの周りにねじ込みます（図 14）。軸受が穴に圧入で留まり、キャップの抜け止めになります。

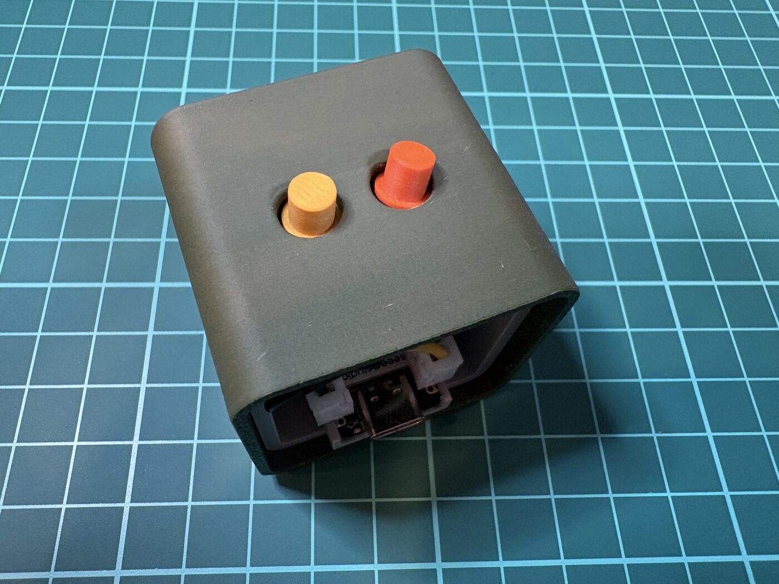
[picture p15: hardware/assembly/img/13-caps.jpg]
外装の天面の丸穴に 2 つのキャップだけが入っている


図 13: キャップを先に穴へ入れます。

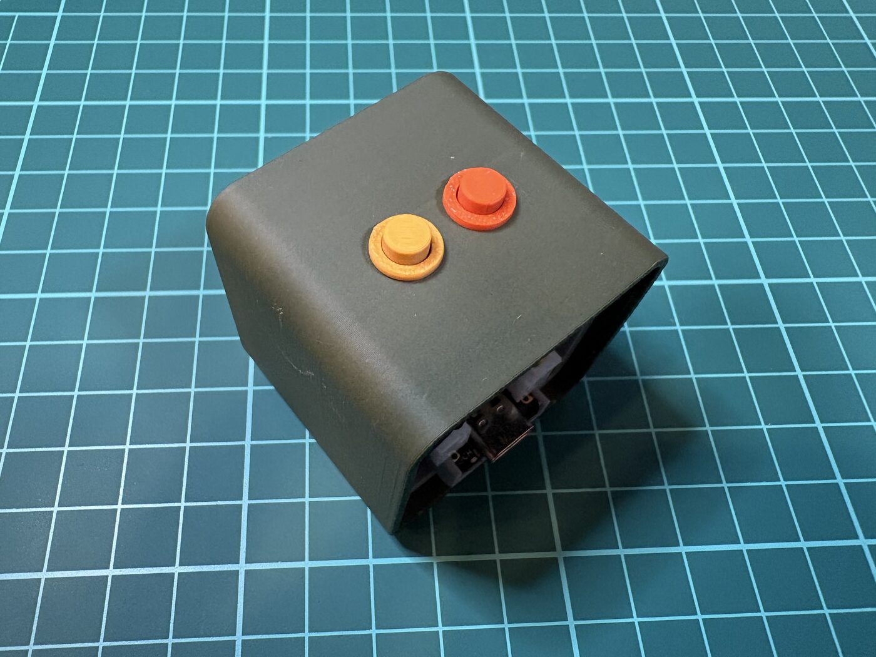
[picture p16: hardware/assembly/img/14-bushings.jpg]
キャップの周りに軸受のリングがはまり、ボタンが完成している


図 14: 軸受をねじ込むとボタンが完成します。

## 10. 背面パネルをはめる

背面パネルは USB-C の穴が下に来る向きではめます（図 15）。

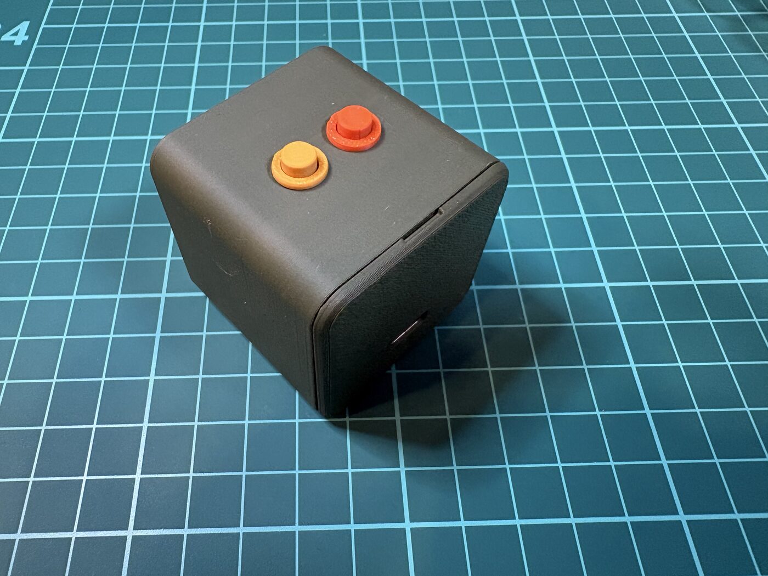
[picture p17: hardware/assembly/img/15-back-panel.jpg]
背面パネルがはまった状態。USB-C の穴が下側にある


図 15: 背面パネルは USB-C の穴を下にしてはめます。

## 11. ファームウェアを書き込む

背面の穴から USB-C ケーブルをつなぎ、[インストーラページ](https://cespresso.github.io/CLumo/)からファームウェアを書き込みます。書き込みが終わって表示が出れば完成です（図 16）。

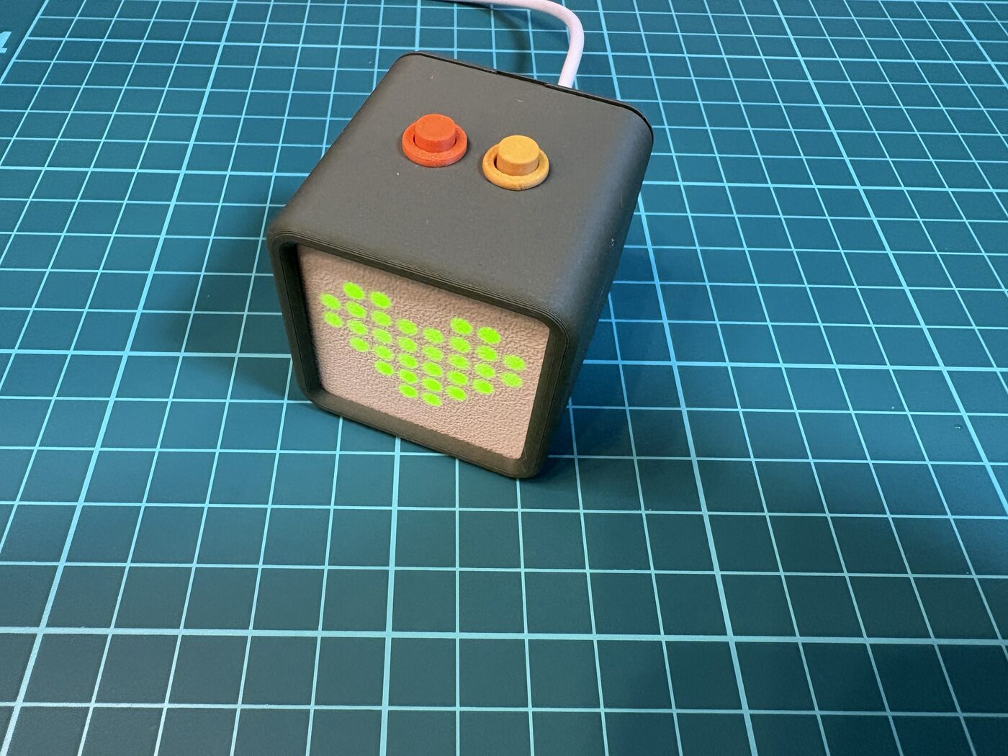
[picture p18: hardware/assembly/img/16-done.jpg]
完成した CLumo。USB ケーブルがつながり、マトリクスにハートが表示されている


図 16: 書き込みが終わると表示が出ます。

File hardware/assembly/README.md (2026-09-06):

# CLumo assembly guide

English | [日本語](README.ja.md)

The main skills you need are soldering pin headers and crimping JST XH contacts. The connections are drawn in the wiring diagram in step 3.

You could build it with no connectors and solder every wire directly, but the difficulty and the cable routing make that a poor option. This guide uses connectors throughout.

## What you need

Figure 1 shows the parts laid out. The photo does not show the full count of JST parts, so check the tables below for quantities.

All parts: printed parts, XIAO, matrix module, wires, tactile switches, JST parts

Figure 1: The printed parts and electronics laid out. Only some of the JST parts are shown.

### Electronics

| Part | Qty | Notes |
|---|---|---|
| Seeed XIAO ESP32-C3 | 1 | |
| MAX7219 8x8 LED matrix module | 1 | The common 32 mm square module |
| Tactile switch, 6x6 mm | 2 | Four-leg type |
| Heat-shrink tubing | a little | To cover the GND splice |

### JST XH 2.54 mm

A compatible kit covers everything. All board headers are straight.

| Part | Qty | Used for |
|---|---|---|
| 5-pin board header | 2 | XIAO left column / matrix IN |
| 2-pin board header | 1 | XIAO right column |
| 5-pin housing | 2 | XIAO left column / matrix side |
| 2-pin housing | 1 | XIAO right column |
| 3-pin housing | 2 | Buttons. Only the two outer positions are used; the middle stays empty |
| Crimp contacts | 16 | |

### Wire

About 5 cm for every run. When I built mine, anything shorter was awkward to handle. You can go a bit longer, but too long and it will not fit in the case.

| Type | Qty | Run |
|---|---|---|
| Coloured | 4 | XIAO to matrix (3V3 / D10 / D9 / D8) |
| Coloured | 2 | XIAO to each button (D1 / D2) |
| Black | 4 | GND. One from the XIAO, splitting into three for the matrix and both buttons |

### Printed parts

There are five kinds, shown in Figure 2. Each button is two parts, a bushing and a cap, and printing them in a different colour gives the box an accent. The 3D data is [`clumo.3mf`](../models/clumo.3mf).

Printed parts: outer shell, back panel, white tray, grey frame, button bushings and caps

Figure 2: The printed parts are the shell, back panel, tray, frame, and two button sets.

| Part | Colour in photos | Role |
|---|---|---|
| Shell | dark green | Two round button holes on top, large openings front and back |
| Back panel | dark green | Closes the back opening. The slot is the USB-C port |
| Tray | white | A shallow box the matrix drops into. Its floor is the diffuser |
| Frame | grey | Carries the XIAO and the switches. All wiring happens here |
| Button bushing | yellow / orange | A ring that fits the round hole in the shell |
| Button cap | yellow / orange | The part you press |

### Tools

Soldering iron, a crimp tool for JST XH, cutters, and a wire stripper.

## Overview

1. Solder a header to the matrix and drop it into the tray
2. Solder headers to the XIAO
3. Build the harness
4. Fit the switches into the frame
5. Snap the XIAO into the frame
6. Connect everything inside the frame
7. Mate the tray and the frame
8. Slide it into the shell
9. Fit the buttons
10. Fit the back panel
11. Flash the firmware

## 1. Solder a header to the matrix and drop it into the tray

The module has two identical header rows. The 5-pin header goes on the row whose silkscreen reads VCC / GND / **DIN** / CS / CLK (Figure 3). The other row is DOUT, the output for chaining a second module. A header on that side lights nothing.

Back of the matrix module next to the white tray, with a 5-pin header on the DIN side

Figure 3: The header goes on the side marked DIN. Here the left column is DOUT and the right column is DIN.

With the header on, drop the module into the tray LEDs down. It is seated when the back of the board faces up and the connector sticks out over the rim of the tray.

## 2. Solder headers to the XIAO

Neither header starts at the end of its column, so check the positions before soldering. Figure 4 is the underside, the face with the pin names printed on it.

Underside of the XIAO ESP32-C3, with solder on the five pads from GND to D8 on the left and on D1 and D2 on the right

Figure 4: The 5-pin header covers GND through D8 on the left column; the 2-pin header covers D1 and D2 on the right.

| Column | Header | Pads | Goes to |
|---|---|---|---|
| The 5V column | 5-pin | GND / 3V3 / D10 / D9 / D8 | matrix (GND is shared with the buttons) |
| The D0 column | 2-pin | D1 / D2 | buttons |

## 3. Build the harness

Follow the wiring diagram in Figure 5. Four coloured wires run straight between the XIAO's 5-pin and the matrix's 5-pin. GND is different: one black wire leaves the XIAO and splits three ways to the matrix and both buttons. Cover the splice with heat-shrink.

Wiring diagram: XIAO GND / 3V3 / D10 / D9 / D8 to the matrix VCC / GND / DIN / CS / CLK, and D1 / D2 to the two buttons

Figure 5: Five wires go to the matrix and two to the buttons; only GND splits from one wire into three.

The buttons use 3-pin housings, but only the two outer positions are crimped; the middle stays empty. Two XH pitches of 2.54 mm match the spacing of the tactile switch legs. Each button housing therefore carries one coloured wire from D1 or D2 and one black wire from the GND splice. The finished harness looks like Figure 6.

The finished harness: two 5-pin, one 2-pin, and two 3-pin housings, with the GND splice covered in heat-shrink

Figure 6: The harness has five housings, and only the black GND wire branches.

## 4. Fit the switches into the frame

The top plate of the frame has two square pockets for the switches. Push a tactile switch into each from the outside (Figure 7).

Two tactile switches seated in the top plate of the frame, legs in the slots on either side

Figure 7: Pushed in from the outside, each switch's legs fall into the slots either side.

Now push the harness's 3-pin housings into the same slots from inside the frame. The crimp contacts press against the switch legs, and the fit of the printed slots alone holds the housing (Figure 8). Nothing is soldered.

The frame seen from below, with two 3-pin housings pushed up into the slots

Figure 8: The 3-pin housings go in from below and are held by the fit of the slots.

Orient each housing so its two crimped positions meet the switch legs. If the empty middle position lines up with the middle slot, it is the right way round.

The contacts poke out of the slots next to the legs, so you can solder them to the switch if you like. The PLA is right next to the joint, though, and it is hard to do without melting it. The crimped fit works well on its own, so this is your call.

## 5. Snap the XIAO into the frame

Inside the frame is a cradle with catches for the XIAO. Point the USB-C toward the back, the open side of the frame, keep the shielded face up, and press the board in. It is a little stiff, but it snaps into place (Figure 9).

The XIAO snapped into the frame, USB-C facing forward and both headers facing up

Figure 9: The XIAO snaps in with its USB-C facing the back.

There is only one correct orientation. Reversed, the USB-C will not line up with the hole in the back panel.

## 6. Connect everything inside the frame

Space inside the frame is tight; you are working in the gap between the top plate and the XIAO.

> The XIAO's 5-pin connector and the button housings overlap, so there is a knack to it. There may be other ways, but this is how I do it.
> 1. Push both 3-pin button housings in first (step 4)
> 2. Plug the D1 / D2 housing into the XIAO's 2-pin header
> 3. Last, plug the 5-pin into the XIAO, sliding it in from the USB-C side

When done it looks like Figure 10. Leave the five wires for the matrix trailing out the top.

Inside the frame, both XIAO connectors and both button housings are connected, with the matrix cable coming out the top

Figure 10: Everything except the matrix cable is connected.

## 7. Mate the tray and the frame

Plug the harness into the matrix's 5-pin connector and bring the tray and frame together face to face (Figure 11).

The white tray and grey frame joined by a JST connector, side by side

Figure 11: A single connector joins the tray and the frame.

## 8. Slide it into the shell

The shell has two openings. The slightly smaller one at the front is the LED window; the wide one at the back is where the assembly goes in. Line up these four things and push it in through the wide opening (Figure 12).

| Align | Position |
|---|---|
| Tray (white) | small front opening |
| Frame (grey) | wide back opening |
| Face with the two round holes | up |
| USB-C | down |

The assembly inside the shell, with the switches visible through the top holes and the XIAO's USB-C visible at the back

Figure 12: Seated correctly, the switches show through the top holes and the USB-C sits low in the back opening.

## 9. Fit the buttons

The buttons go in from the outside. Drop a cap into each round hole on top (Figure 13), then twist a bushing ring in around it (Figure 14). The bushing is a press fit in the hole and keeps the cap from falling out.

Two caps sitting in the round holes on top of the shell, without bushings

Figure 13: The caps go into the holes first.

Bushing rings fitted around the caps, completing the buttons

Figure 14: Twisting in the bushings finishes the buttons.

## 10. Fit the back panel

The back panel goes on with the USB-C slot at the bottom (Figure 15).

The back panel fitted, USB-C slot at the bottom

Figure 15: The back panel fits with the USB-C slot downward.

## 11. Flash the firmware

Plug a USB-C cable in through the back and flash the firmware from the [installer page](https://cespresso.github.io/CLumo/). When the display comes on, you are done (Figure 16).

The finished CLumo with a USB cable attached, showing a heart on the matrix

Figure 16: Once flashed, the display comes on.

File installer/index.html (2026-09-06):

  

# CLumo インストーラ

# CLumo Installer

ブラウザから CLumo にファームウェアを書き込みます。ツールのインストールは不要です。

Flash CLumo's firmware from your browser. Nothing to install.

STEP 1 / 2 · ファームウェアを選ぶ STEP 1 / 2 · CHOOSE A FIRMWARE



## 単独版アプリ不要

## StandaloneNo app needed

ボタン 2 つだけで完結します。デジタルペット、ポモドーロタイマー、サイコロの 3 つのモード。Bluetooth もスマホも使いません。

Everything runs on the two buttons: a digital pet, a pomodoro timer, and dice. No Bluetooth, no phone.

単独版を書き込むFlash standalone



## アプリ協調版Android アプリ連携

## CompanionWith the Android app

Android アプリ「CLumo」と Bluetooth でつながります。ポモドーロ、タイマー、アプリで描いた絵を映すマイ表示、音に合わせて動くビジュアライザ。アプリは 最新の Release (https://github.com/Cespresso/CLumo/releases/latest) の clumo.apk です。

Pairs with the CLumo Android app over Bluetooth: pomodoro, a timer, pictures you draw in the app, and a visualizer that moves with your audio. The app is clumo.apk in the latest release (https://github.com/Cespresso/CLumo/releases/latest).

アプリ協調版を書き込むFlash companion

どちらを選んでも、あとからこのページで何度でも書き換えられます。迷ったら単独版から。

Whichever you pick, you can come back here and switch as often as you like. If in doubt, start with standalone.

STEP 2 / 2 · 書き込み方法を選ぶ STEP 2 / 2 · CHOOSE HOW TO FLASH

選択中: 単独版アプリ協調版 · 選び直す Selected: standalonecompanion · change



## PC から推奨

## From a PCRecommended

本家の ESP Web Tools（Web Serial）を使います。PC の Chrome / Edge / Opera で動きます。スマホは使えません。

Uses the original ESP Web Tools over Web Serial. Works in Chrome, Edge, and Opera on a desktop. Phones are not supported.

この方法で進むContinue



## PC または Android からWebUSB

## From a PC or AndroidWebUSB

PC に加えて Android の Chrome（USB-OTG）からも書き込めます。コミュニティ製のフォーク（tasmota-esp-web-tools）を使います。

Also works from Chrome on Android over USB-OTG, using a community fork (tasmota-esp-web-tools).

この方法で進むContinue

書き込まれるファームウェアはどちらでも同じです。迷ったら「PC から」を、スマホで書き込みたいときは「PC または Android から」を選んでください。

The firmware is the same either way. If in doubt pick "From a PC"; pick the other one when you want to flash from a phone.

単独版アプリ協調版をPC からPC または Android から書き込みます。 選び直す Flashing the standalonecompanion firmware from a PCfrom a PC or Android. Change

インストールInstall このブラウザは未対応です。PC は Chrome / Edge / Opera、スマホは Android の Chrome をご利用ください。iOS、Safari、Firefox では使えません。 This browser is not supported. Use Chrome, Edge, or Opera on a desktop, or Chrome on Android. iOS, Safari, and Firefox cannot flash. HTTPS で開いたときだけ使えます。 Only available over HTTPS.

## 手順

## Steps

1. CLumo を USB ケーブルでつなぐ
  - PC: そのままつなぐ
  - Android: USB-OTG ケーブルでつなぎ、Chrome でこのページを開く
2. 上の「インストール」を押す
3. 表示されたシリアルポート / USB デバイスを選ぶ
4. 書き込みが終わるのを待つ。自動で再起動します
5. 「Select Port」のダイアログが出たら、書き込みは終わっています。同じ CLumo を選び直すと完了画面になります。閉じても構いません
1. Connect CLumo over USB
  - PC: plug it straight in
  - Android: use a USB-OTG cable and open this page in Chrome
2. Press "Install" above
3. Pick the serial port or USB device it offers
4. Wait for flashing to finish. The device restarts on its own
5. If a "Select Port" dialog appears, flashing is already done. Pick the same CLumo again to reach the completion screen, or just close it

## 書き込んだあと

## After flashing

1. 「インストール完了」のあとに空のダイアログが出たら閉じて構いません。本体はもう動いています
2. マトリクスが点灯し、最初のモードが表示されます
3. 白ボタンを 1 秒長押しでモードが切り替わります。ペット → ポモドーロ → サイコロの順です
4. 各モードでの橙 / 白の操作は 単独版の README (https://github.com/Cespresso/CLumo/tree/main/standalone#readme) にまとめてあります
1. If an empty dialog appears after "Installation complete", just close it. The device is already running
2. The matrix lights up with the first mode
3. Hold the white button for a second to switch modes: pet, pomodoro, dice
4. What orange and white do in each mode is in the standalone README (https://github.com/Cespresso/CLumo/tree/main/standalone#readme)
1. 「インストール完了」のあとに空のダイアログが出たら閉じて構いません。本体はもう動いています
2. マトリクスに接続待ちのアイコンが出て、最初のペアリングまでそのまま待ちます
3. Android アプリ「CLumo」をインストールします。最新の Release (https://github.com/Cespresso/CLumo/releases/latest) の clumo.apk です
4. アプリを開いて「CLumo を探す」を押し、見つかった CLumo に接続します。パスキーは 123456
5. ポモドーロ、タイマー、マイ表示、ビジュアライザをアプリから使えます。本体の表示の意味は 協調版の README (https://github.com/Cespresso/CLumo/tree/main/companion#readme) にまとめてあります
1. If an empty dialog appears after "Installation complete", just close it. The device is already running
2. The matrix shows the waiting-for-connection icon and stays on it until the first pairing
3. Install the CLumo Android app: clumo.apk from the latest release (https://github.com/Cespresso/CLumo/releases/latest)
4. Open the app, tap "Find CLumo", and connect to the one it finds. The passkey is 123456
5. Pomodoro, timer, your own pictures, and the visualizer are then all in the app. What the device shows is explained in the companion README (https://github.com/Cespresso/CLumo/tree/main/companion#readme)

## デバイス情報

## Device

- MCUESP32-C3
- LED8x8 マトリクス（MAX7219）8x8 matrix (MAX7219)
- ボタンButtons2 つTwo
- Bluetooth使いませんNot used
- BLE 名BLE nameCLumo-XXXX（末尾は個体ごと）CLumo-XXXX (suffix per unit)
- パスキーPasskey123456

対応環境: PC の Chrome / Edge / Opera（Web Serial）。加えて Android の Chrome（USB-OTG / WebUSB）。 iOS、Safari、Firefox では使えません。
Android では充電専用ではなくデータ通信対応の OTG ケーブルを使ってください。
初回の書き込みではフラッシュ全体を消去します。保存されていた設定はリセットされます。

Works in: Chrome, Edge, and Opera on a desktop (Web Serial). Also Chrome on Android (USB-OTG / WebUSB). Not on iOS, Safari, or Firefox.
On Android, use an OTG cable that carries data, not a charge-only one.
The first flash erases the whole flash memory, so any saved settings are reset.

Powered by ESP Web Tools (https://github.com/esphome/esp-web-tools) (Apache-2.0) · GitHub (https://github.com/Cespresso/CLumo)

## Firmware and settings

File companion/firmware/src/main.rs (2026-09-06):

use esp_idf_hal::delay::FreeRtos;
use esp_idf_hal::peripherals::Peripherals;
use esp_idf_svc::nvs::{EspDefaultNvsPartition, EspNvs};
use std::time::Instant;

use crate::display_routing::DisplayWrite;
use crate::handlers::Runtime;
use crate::mode::Mode;
use crate::utils::bluetooth::{
    BleCommand, BluetoothManager, PomodoroCommand, TimerCommand, BUTTON_MAIN, BUTTON_SUB,
};
use crate::utils::button::Buttons;
use crate::utils::device_id;
use crate::utils::led::Display;

mod assets;
mod countdown;
mod display_routing;
mod display_state;
mod handlers;
mod mode;
mod mode_values;
mod settings_values;
mod utils;
mod visualizer_values;

/// Blink interval for the disconnected icon during connection setup (ms).
const CONNECTION_BLINK_MS: u128 = 400;
/// Briefly show link loss, then return the matrix to its standalone mode frame.
const DISCONNECTED_NOTICE_MS: u128 = 1_200;
/// NimBLE advertises only while unconnected, so a client that connects and never
/// completes the encrypted initial sync locks every other client out until the
/// device is power-cycled. Long enough not to preempt a slow passkey entry.
const CLIENT_READY_TIMEOUT_MS: u128 = 60_000;

fn disconnected_icon(bonded: bool) -> &'static [u8; 8] {
    if bonded {
        &assets::ICON_DISCONNECTED_BONDED
    } else {
        &assets::ICON_DISCONNECTED
    }
}

fn main() -> Result<(), Box<dyn std::error::Error>> {
    esp_idf_svc::sys::link_patches();
    esp_idf_svc::log::EspLogger::initialize_default();
    log::info!("=== CLumo Companion Starting ===");

    let peripherals = Peripherals::take().unwrap();
    FreeRtos::delay_ms(200);

    // Initialize LED matrix (MAX7219 via SPI)
    let mut display = Display::new(
        peripherals.spi2,
        peripherals.pins.gpio8.into(),
        peripherals.pins.gpio9.into(),
        peripherals.pins.gpio10.into(),
    )?;
    log::info!("LED matrix initialized");
    display.show(&assets::ICON_DISCONNECTED);

    // Initialize NVS, device identity, and Mode Manager
    let nvs_partition = EspDefaultNvsPartition::take()?;
    let mut nvs_device = EspNvs::new(nvs_partition.clone(), "DEVICE", true)?;
    let device_id = device_id::load_or_create(&mut nvs_device)?;
    let nvs_mode = EspNvs::new(nvs_partition.clone(), "STATE", true)?;
    let mut mode_manager = mode::ModeManager::new(nvs_mode)?;
    log::info!("Mode system initialized: {}", mode_manager.current().name());
    display.set_intensity(mode_manager.brightness());

    let mut runtime = Runtime::new(nvs_partition.clone())?;

    // Initialize BLE
    let ble = BluetoothManager::init(
        mode_manager.current() as u8,
        runtime.display_committed_frame(),
        runtime.pomodoro_status(),
        runtime.timer_status(),
        mode_manager.brightness(),
        device_id,
    )?;
    log::info!("BLE initialized");
    let mut ble_bonded = ble.has_bonded_peer();
    display.show(disconnected_icon(ble_bonded));

    // main = red, sub = white
    let mut buttons = Buttons::new(peripherals.pins.gpio3.into(), peripherals.pins.gpio4.into())?;
    log::info!("Buttons initialized (red=GPIO3, white=GPIO4)");

    let mut ble_connected = false;
    let mut client_ready = false;
    let mut connection_icon_on = true;
    let mut last_connection_blink = Instant::now();
    let mut disconnected_notice_started = Some(Instant::now());
    let mut client_ready_wait_started: Option<Instant> = None;

    // Main loop
    loop {
        let main_pressed = buttons.red.poll();
        let sub_pressed = buttons.white.poll();

        // Drain BLE commands
        while let Some(cmd) = ble.take_command() {
            match cmd {
                BleCommand::ConnectionChanged(connected) => {
                    ble_connected = connected;
                    client_ready = false;
                    connection_icon_on = true;
                    last_connection_blink = Instant::now();
                    client_ready_wait_started = if connected {
                        Some(Instant::now())
                    } else {
                        None
                    };
                    disconnected_notice_started = if connected {
                        None
                    } else {
                        runtime.cancel_display_preview();
                        Some(Instant::now())
                    };
                    display.show(disconnected_icon(ble_bonded));
                }
                BleCommand::BondChanged(bonded) => {
                    ble_bonded = bonded;
                    if !client_ready {
                        display.show(disconnected_icon(ble_bonded));
                    }
                }
                BleCommand::AuthenticationFailed => {
                    ble_connected = false;
                    client_ready = false;
                    client_ready_wait_started = None;
                    runtime.cancel_display_preview();
                    disconnected_notice_started = Some(Instant::now());
                    display.show(disconnected_icon(ble_bonded));
                }
                BleCommand::ClientReady => {
                    if ble_connected && !client_ready {
                        client_ready = true;
                        client_ready_wait_started = None;
                        display.show(&runtime.on_enter(mode_manager.current()));
                    }
                }
                BleCommand::SwitchMode(m) => {
                    let new_mode = Mode::from_u8(m);
                    // Nothing rides on MODE but the mode itself, so a same-value write
                    // has nothing to do.
                    if new_mode == mode_manager.current() {
                        continue;
                    }
                    runtime.cancel_display_preview();
                    if let Err(e) = mode_manager.switch_to(new_mode) {
                        log::error!("BLE switch_to failed: {:?}", e);
                    }
                    ble.notify_mode_change(mode_manager.current() as u8);
                    if client_ready || (!ble_connected && disconnected_notice_started.is_none()) {
                        display.show(&runtime.on_enter(mode_manager.current()));
                    }
                }
                BleCommand::CommitDisplayFrame(frame) => {
                    // Nothing is drawn here: Display picks the committed frame up through
                    // on_enter, or through the handler's dirty flag while it is already up.
                    runtime.commit_display(frame);
                    ble.notify_display_frame(&frame);
                }
                BleCommand::PreviewDisplayFrame(frame) => {
                    if display_routing::accepts(mode_manager.current() as u8, DisplayWrite::Preview)
                    {
                        runtime.on_display_preview(frame);
                    }
                }
                BleCommand::VisualizerColumns(heights) => {
                    if display_routing::accepts(
                        mode_manager.current() as u8,
                        DisplayWrite::Visualizer,
                    ) {
                        runtime.on_visualizer_columns(heights);
                    }
                }
                BleCommand::SetBrightness(level) => match mode_manager.set_brightness(level) {
                    Ok(applied) => {
                        display.set_intensity(applied);
                        ble.notify_brightness_change(applied);
                        log::info!("Brightness set to {}", applied);
                    }
                    Err(e) => {
                        log::warn!("Brightness persistence failed: {:?}", e);
                        ble.notify_brightness_change(mode_manager.brightness());
                    }
                },
                BleCommand::Pomodoro(cmd) => {
                    // Reset is accepted from any mode: Pomodoro keeps running in the
                    // background while another mode is shown, so stopping it can't
                    // require switching back first. Everything else stays mode-scoped.
                    if mode_manager.current() == Mode::Pomodoro
                        || matches!(cmd, PomodoroCommand::Reset)
                    {
                        runtime.on_pomodoro_command(cmd);
                    } else {
                        // Ignored outside Pomodoro mode; restore the status value so
                        // READ stays accurate.
                        ble.set_pomodoro_status(&runtime.pomodoro_status());
                    }
                }
                BleCommand::Timer(cmd) => {
                    if mode_manager.current() == Mode::Timer || matches!(cmd, TimerCommand::Cancel)
                    {
                        runtime.on_timer_command(cmd);
                    } else {
                        ble.set_timer_status(&runtime.timer_status());
                    }
                }
            }
        }

        // Pomodoro and Timer own their state, so they handle their own presses
        // and keep working while disconnected. Display and Visualizer content
        // lives in the app, so their presses are forwarded and the app decides
        // what they mean.
        // The mode must be read after the BLE command drain so a press is attributed
        // to the currently rendered mode.
        let mode = mode_manager.current();
        let standalone_press =
            (main_pressed || sub_pressed) && matches!(mode, Mode::Pomodoro | Mode::Timer);
        for (pressed, is_main) in [(main_pressed, true), (sub_pressed, false)] {
            if !pressed {
                continue;
            }
            log::info!(
                "[{}] {} button",
                mode.name(),
                if is_main { "Main" } else { "Sub" }
            );
            match mode {
                Mode::Pomodoro | Mode::Timer => {
                    runtime.on_button(mode, is_main);
                }
                Mode::Display | Mode::Visualizer => {
                    if client_ready {
                        ble.notify_button(mode, if is_main { BUTTON_MAIN } else { BUTTON_SUB });
                    } else {
                        log::info!("Button press dropped: no synced client");
                    }
                }
            }
        }

        // Display update
        if let Some(frame) = runtime.tick(mode) {
            if client_ready || (!ble_connected && disconnected_notice_started.is_none()) {
                display.show(&frame);
            }
        }

        // A device that has never bonded has no app to lose, so the notice stays up
        // until a phone pairs or a button puts the device to standalone use.
        if !ble_connected
            && disconnected_notice_started.is_some_and(|started| {
                (ble_bonded && started.elapsed().as_millis() >= DISCONNECTED_NOTICE_MS)
                    || standalone_press
            })
        {
            disconnected_notice_started = None;
            display.show(&runtime.on_enter(mode));
        }

        if ble_connected
            && !client_ready
            && client_ready_wait_started
                .is_some_and(|started| started.elapsed().as_millis() >= CLIENT_READY_TIMEOUT_MS)
            && ble.disconnect_stalled_client()
        {
            // Only disarm once the stack accepted the request; a refused disconnect
            // leaves the timer armed so the next pass tries again.
            client_ready_wait_started = None;
        }

        // Blink the disconnected icon while the BLE link, authentication, and
        // Android initial GATT synchronization are still in progress.
        if ble_connected
            && !client_ready
            && last_connection_blink.elapsed().as_millis() >= CONNECTION_BLINK_MS
        {
            connection_icon_on = !connection_icon_on;
            last_connection_blink = Instant::now();
            if connection_icon_on {
                display.show(disconnected_icon(ble_bonded));
            } else {
                display.show(&assets::PATTERN_ALL_OFF);
            }
        }

        if let Some(status) = runtime.poll_pomodoro_status() {
            ble.notify_pomodoro_status(&status);
        }
        if let Some(status) = runtime.poll_timer_status() {
            ble.notify_timer_status(&status);
        }

        FreeRtos::delay_ms(50);
    }
}

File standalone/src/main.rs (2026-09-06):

use esp_idf_hal::delay::FreeRtos;
use esp_idf_hal::peripherals::Peripherals;
use esp_idf_svc::nvs::{EspDefaultNvsPartition, EspNvs};

use crate::utils::button::{Buttons, PressType};
use crate::utils::led::Display;

mod assets;
mod handlers;
mod mode;
mod mode_values;
mod progress;
mod utils;

fn main() -> Result<(), Box<dyn std::error::Error>> {
    esp_idf_svc::sys::link_patches();
    esp_idf_svc::log::EspLogger::initialize_default();
    log::info!("=== CLumo Starting ===");

    let peripherals = Peripherals::take().unwrap();
    FreeRtos::delay_ms(200);

    // Initialize LED matrix (MAX7219 via SPI)
    let mut display = Display::new(
        peripherals.spi2,
        peripherals.pins.gpio8.into(),
        peripherals.pins.gpio9.into(),
        peripherals.pins.gpio10.into(),
    )?;
    log::info!("LED matrix initialized");

    // Initialize NVS and Mode Manager
    let nvs_partition = EspDefaultNvsPartition::take()?;
    let nvs_mode = EspNvs::new(nvs_partition, "CLUMO", true)?;
    let mut mode_manager = mode::ModeManager::new(nvs_mode)?;
    log::info!("Mode system initialized: {}", mode_manager.current().name());

    // Initialize buttons (red=GPIO3, white=GPIO4)
    let mut buttons = Buttons::new(peripherals.pins.gpio3.into(), peripherals.pins.gpio4.into())?;
    log::info!("Buttons initialized (red=GPIO3, white=GPIO4)");

    let mut runtime = handlers::Runtime::new();
    display.show(&runtime.on_enter(mode_manager.current()));

    // Main loop
    loop {
        let red_press = buttons.red.poll();
        let white_press = buttons.white.poll();

        // White long-press: cycle mode (universal, consumed before mode dispatch)
        let white_press = if let Some(PressType::Long) = white_press {
            let next = mode_manager.current().next();
            if let Err(e) = mode_manager.switch_to(next) {
                log::error!("Failed to switch mode: {:?}", e);
            }
            // Mode icon splash, then hand over to the handler
            display.show(&mode_manager.current().icon());
            FreeRtos::delay_ms(500);
            display.show(&runtime.on_enter(mode_manager.current()));
            None // consume the press
        } else {
            white_press
        };

        // Mode-specific button handling
        if let Some(press) = red_press {
            log::info!("[{}] Red: {:?}", mode_manager.current().name(), press);
            runtime.on_red_button(mode_manager.current(), press);
        }
        if let Some(press) = white_press {
            log::info!("[{}] White: {:?}", mode_manager.current().name(), press);
            runtime.on_white_button(mode_manager.current(), press);
        }

        // Display update
        if let Some(frame) = runtime.tick(mode_manager.current()) {
            display.show(&frame);
        }

        FreeRtos::delay_ms(50);
    }
}

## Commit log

2026-09-06 redraw the installer page in both languages
    The installer was Japanese only and had drifted from the firmware: its
    companion guide listed three functions without pomodoro, and it still
    called the main button red where the READMEs now say orange. Every text
    block exists twice with a lang attribute; the page picks Japanese or
    English from ?lang=, then a remembered choice, then the browser, and the
    toggle carries the firmware and method choices along.
    The look follows the app and the READMEs: the same device art on the
    hero and on each choice card, the app's palette and rounded type, pill
    buttons in coral. The post-flash guides now hand over to the standalone
    and companion READMEs instead of r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
2026-09-06 recognise a reset CLumo and let a device be removed
    A device that had its flash erased comes back with a new firmware id and
    no bond. The app matched known devices by id alone, so after the user
    forgot the stale pairing in Android settings and paired again, the same
    CLumo appeared as a second card, and its alias, colours and main-device
    role stayed on the old id with no way to clean up.
    Known devices now merge on id or MAC, and the registry moves the
    per-device settings to the new id before the record is replaced, so a
    reset CLumo picks up where it left off. The device menu gains "Remove
    this device", which drops the session, the record and the settings after
    a confirmation that says the An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
2026-09-06 let the list tidy itself
    Removing a device meant opening it first, which is backwards for the
    case that wants it: a CLumo you can no longer reach. Holding a card now
    puts the list in a tidying mode where each card's right edge is a remove
    button and the header offers Done; the back gesture leaves too, and the
    mode closes itself once nothing is left to tidy.
    A mode rather than a per-card button because reordering is coming, and
    long-press-and-drag is how that will be asked for. Inside a mode the
    gesture is free; on a plain card it would have been spoken for. The
    confirmation and what it removes are the device screen's, unchanged.
2026-09-06 say less in the comments
    Several of the comments added with the idle screens and the device
    tidying were talking about things that are not in the code: why a mode
    was chosen over a button on every card, what reordering will need later,
    what an older build used to store. Others restated the line underneath
    them, and two carried the same explanation as the definition they call.
    All of that is gone.
    What is left is what the code cannot say: that the settings have to move
    before the record is replaced, that leaving idle marks the frame dirty
    even though the pixel count does not change, that a phone remembers the
    GAP name it read. The sentence in DeviceNaming had lost its main clause
    when a vers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
    [main.rs]
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2026-09-06 drop long press and give the sub button reset and cancel
    [main.rs]
2026-09-06 name the main/sub button mapping and tighten button debounce
    [main.rs]
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2026-09-06 gate button forwarding on synced client and tighten button dispatch types
    [main.rs]
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2026-09-06 apply code review fixes to button-role helpers
    Return the Pattern itself from cyclePattern instead of its id, add an
    atomic cycleSelection to PatternRepository, narrow BUTTON payload mode
    validation to the two modes the firmware actually sends, move parsing
    onto ButtonEvent with an isMain accessor, and derive the sensitivity
    rounding factor from the step constant instead of hard-coding it.
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2026-09-06 keep new characteristics from shifting existing ATT handles
    Creating BUTTON ahead of DEVICE_ID moved DEVICE_ID's attribute handle, so a
    client reconnecting from a GATT cache written against older firmware read the
    stale handle, hit BUTTON's unreadable value attribute, and failed initial sync
    into a reconnect loop. Append new characteristics instead, and refresh the cache
    once when an optional characteristic is missing so its features can come alive.
2026-09-06 add per-mode button role tags to the device screen
    Each mode gives the two physical buttons a different job, and the app never said
    which was which. Two chips under the device figure name them, with the coral dot
    standing for the main button and the white one for the sub button. They follow
    the selected mode optimistically, so the wording changes on tap rather than
    waiting for the device to confirm, and they dim with the rest of the controls
    while disconnected.
    The chips wrap instead of sitting in a fixed row. Two of them stop fitting side
    by side as the font scale grows, and a Row hands the leftover width to its second
    child, which breaks that label mid-word.
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2026-09-06 track the companion firmware lockfile
    The firmware is a binary crate, so its resolved dependency versions belong in the
    repo: anyone flashing a build should get the same tree rather than whatever the
    registry serves that day. The file has been sitting in the working copy since the
    firmware landed in c2f8e7e and was never added.
    standalone has no lockfile checked in either, but it has not been built in this
    checkout, so there is nothing to add for it yet.
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2026-09-06 explain the main CLumo setting in the device list
    The star toggle and the device menu item had no explanation anywhere, and
    setting a main device changes nothing visible when only one device is
    registered or its colors are untouched.
    Add a "?" badge beside the list heading that opens a short explanation, and
    mark the main device's card with a "メイン" pill so the filled star is
    readable without tapping it. The pill sits on its own line because the name
    column is only about 130dp wide and already wraps for longer device names.
    Extract the "?" affordance out of the mode help header as HelpBadge, and fold
    the chrome shared by the three dialogs into DialogCard so the new info dialog
    does no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
2026-09-06 resolve the primary device to a connectable target
    A widget has no address to hand in, so something has to turn the stored primary
    id into a device. A dangling id counts as unset, a single known device answers
    for itself, and several with none designated stay ambiguous.
2026-09-06 add widget commands and gate them against a down link
    A powered-off CLumo must not attract repeated connection attempts, so a failed
    attempt starts a cooldown that only an explicit retry may bypass. The cooldown
    treats a timestamp in the future as expired, since elapsedRealtime resets on
    reboot and would otherwise lock the user out.
2026-09-06 add home screen widgets driven by the device hub service
    Two widgets: a control widget that follows the device's mode and operates it,
    and a presence widget that draws the device and reports. Neither shows a
    countdown; the face carries the same 64 steps the firmware does.
    The service owns the connection, because a widget has no address to hand in and
    two callers deciding separately would disagree. A tap can start the process from
    cold, so the primary is read from the preference rather than a collector that
    may not have emitted yet. Blocks are observed rather than read at publish time:
    a blocked layout carries no button, so a widget stuck on "Bluetooth is off"
    could not otherwise recover onc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
2026-09-06 draw the widget device the way the app draws it
    The widgets showed a bare dot grid on a plain rounded rect: no inner panel, and
    the two buttons as flat circles inside the enclosure instead of the hardware's
    stepped bumps on top. Next to the app it read as a different product.
    Render the whole device as one bitmap, carrying over the app's proportions
    verbatim, knob ratios on 168 and frame ratios on 188 as ClumoDevice keeps them.
    One bitmap also costs one RemoteViews node where a Box per piece would cost
    several, and nothing short of a canvas can draw the knobs' two tiers.
    Both widgets now share the renderer, so a link that is down cannot look alive on
    one and dead on the other.
2026-09-06 own the app graph in the application, not the hub service
    The hub service built the registry, both repositories, the scanner and the
    preferences and published all five, so binding to a foreground service was the
    price of reading a preference and every screen reached through it into the data
    layer.
    The graph now hangs off the application, built lazily so a cold start that only
    shows onboarding does not read stored devices. The service keeps its foreground
    lifecycle and exposes nothing, so the binder is gone and the UI no longer waits
    on a service connection to draw its first frame. Screens take the dependencies
    they use: five for the device list, four for the device screen.
    Fixes a shadowed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
2026-09-06 run the android tests on every push
    release.yml builds from tags and deploys the installer from main, so nothing ran
    the unit tests and the layering rules added with the last two commits could only
    fail on a developer's machine. A rule that never runs is not a rule.
    The job compiles the instrumented sources as well, which need no device to build.
2026-09-06 derive the device screen's state outside the composable
    DeviceScreen decided what to show inline, in a composable six hundred lines long
    that no test could reach: the selector's mode, the eight connection states, the
    nine failure reasons, and which five of them cannot be retried past.
    DeviceUiStateFactory works it out with every input a parameter, the blink phase
    included, the way the widgets already do. Text is named rather than resolved, so
    the rules stay free of resources and the screen keeps the wording. Twenty-nine
    tests hold them still.
    One behaviour changes: a finished timer now blinks on one ticker rather than two.
    The mirror ran its own, keyed on the device's mode where the sectio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
2026-09-06 give the two brightness scales one home
    The slider works in percent, the device in sixteen levels, and the two were
    converted inline at every site that needed them. Nothing said the round trip had
    to be lossless, so a rounding disagreement would land the device's echo of an
    accepted write on a different level than the finger chose and the slider would
    twitch on every write. The dimming rule had drifted into two copies for the same
    reason.
    Brightness now owns both scales, the echo guard, and the dimming rule stated once
    over a fraction so either scale can reach it. The round trip is pinned for all
    sixteen levels and the two dimming entry points are pinned against each other.
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2026-09-06 keep every mode handler alive for the whole run
    A mode switch used to throw the old handler away and build a new one, so
    leaving Pomodoro or Timer silently discarded a countdown that was mid-run and
    reported it as idle. Someone starting a 25 minute work block and glancing at
    the Display pattern came back to a timer that had reset.
    Runtime now owns all four handlers from boot. Switching modes only chooses
    which frame gets rendered; every handler keeps ticking, so Pomodoro and Timer
    survive a detour through another mode. main no longer has to cache the last
    status frame either, since the handler that owns the state can always be
    asked for it.
    [main.rs]
2026-09-06 remember the brightness and the timer duration across reboots
    Brightness reset to full on every power cycle, and the Timer went back to
    05:00 no matter what the app had set, because neither value had anywhere to
    live. A desk gadget that forgets how bright you want it is one you end up
    adjusting every morning.
    ModeManager now stores brightness alongside the current mode, and the Timer
    keeps its configured duration in its own namespace. Execution state stays
    volatile on purpose: coming back from a power cut mid-countdown to a timer
    that is still running would be worse than one that is idle and ready.
    [main.rs]
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2026-09-06 add the two tests that need real hardware to mean anything
    A unit test can prove the session resends a pending command, but it cannot
    prove MainActivity survives building the object graph, and it cannot prove a
    real CLumo answers the handshake the way the README says it does.
    MainActivityLaunchTest catches a composition root that throws on startup,
    which the ViewModel wiring made possible in a way it was not before.
    BleHardwareIntegrationTest is opt-in: without a deviceAddress instrumentation
    argument it skips, so ordinary connected-test runs are unaffected.
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2026-09-06 gather the dependency versions into one file with their constraints
    Deduplication is not the reason. Only two versions were ever written
    twice, androidx.lifecycle and the compose BOM. What the versions lacked
    was a place to say why they are the versions they are.
    Three of them are not free choices. The compose compiler plugin has to
    match the Kotlin that AGP 9 now carries internally. The ktlint engine has
    to be raised past the plugin's own default because Compose Rules 0.6.4 is
    built against 1.8.0. org.json is held at a 2018 release on purpose, since
    a newer one drifts away from the implementation Android ships and the
    local JVM tests exist to stand in for that one. Those constraints were
    s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
2026-09-06 empty both baselines by fixing what they were holding
    The baselines existed to get the tools into CI without a large change
    attached. Thirty-seven findings sat in them. Both files are gone now.
    One was a defect. PatternEditorScreen collected its close events inside a
    LaunchedEffect keyed on the view model alone, so the collector kept
    calling whichever onBack it saw first. It survived only because the pop
    it captures reads a list that outlives recomposition. The same file
    already used rememberUpdatedState twenty lines down.
    The hero image was in drawable/, which means mdpi, which means Android
    was pre-scaling 1080x607 to 3240x1821 in memory on a three-density
    screen. In drawable-nodpi/ it d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
2026-09-06 stop a peer's connection or a stray spi error from rebooting the device
    on_connect unwrapped update_conn_params. That callback runs on the nimble
    host task, and a std panic aborts, so a peer that would not accept the
    parameter update took the device down with it before pairing had even
    finished. Whether the call succeeds is not ours to decide. The negotiated
    interval is an optimization and the link works without it, so the failure
    is logged and the connection stays.
    The two advertiser calls in the same function now propagate instead of
    panicking. Failing to advertise at boot is fatal either way, but init
    already returns Result and an error carries the reason where an abort
    does not.
    show a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
    [led.rs]
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2026-09-06 announce preview support even when part of the initial sync is missing
    The reconnect announce was gated on currentSnapshotOrNull, which returns
    null unless MODE, POMODORO, TIMER, BRIGHTNESS and the committed frame all
    read back. Announcing needs the mode and nothing else, so a single missed
    read on a flaky link dropped the v2 handshake while leaving the app free
    to stream previews.
    What the firmware does then is documented and deliberate: a client that
    has not announced gets the original behaviour, and every DISPLAY write is
    committed and persisted. The two paths are almost disjoint by design,
    since high-rate preview arrived with the handshake and clients that never
    learned it do not stream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
2026-09-06 move to agp 9.4.0 so lint stops failing the build on the version check
    AndroidGradlePluginVersion flags any plugin older than the current stable
    release, and warningsAsErrors turns that into a failed lintDebug. The
    9.4.0 release made every push red without a line of the app changing.
    NewerVersionAvailable is already disabled for reaching the network, but
    this is a separate check and was not.
    The compose compiler plugin at 2.2.21 still matches the Kotlin the new
    plugin carries, so nothing else moves. Unit tests, the instrumentation
    compile, ktlint and lint all pass on the new version.
2026-09-06 keep a widget's device identity when its snapshot goes stale
    A snapshot older than 25 minutes was thrown away whole and replaced with
    disconnectedSnapshot(), a literal with the default colors baked in. So a
    CLumo painted anything but the defaults turned into a stock one on the
    home screen whenever the publisher fell silent, which is what a process
    death does.
    The factory already knew the right answer. Its Disconnected branch copies
    the base that carries the alias and the appearance colors and swaps only
    the layout, because preferences do not expire the way a link report does.
    That branch is now asDisconnected() on the snapshot, and aging a snapshot
    applies the same function instead of retur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
2026-09-06 start the hub from the sessions that need it, not from the launcher
    MainActivity started the foreground service on every launch, connected or
    not. The hub exists to hold BLE links and the microphone claim while the
    app is in the background, and on a phone with no CLumo paired it was
    holding nothing. It now starts when a session has work for it.
    Work is defined by link state, not by the session map. A session stays
    registered after its device goes dark: the connection gives up after
    three retries and reports Error, but only an explicit disconnect removes
    it, and no ViewModel does that on clear. Counting sessions would have
    kept the hub up forever after the first connection. hubHasWorkFor say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
2026-09-06 claim the connected-device type whenever the bluetooth permission is held
    The service is what holds a BLE link open, and connectedDevice is the
    type Android has for that. It was not declared because it cannot be
    claimed unconditionally: Android 14 refuses a startForeground for a type
    whose permission is missing, BLUETOOTH_CONNECT is a runtime permission,
    and a widget tap can start the hub without it. The publisher's own
    PermissionMissing block is the design admitting as much.
    So it joins microphone as a conditional claim. specialUse stays as the
    base every start can make, connectedDevice is added whenever the
    permission is held, and the fallback from the previous change covers the
    moment it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
2026-09-06 split DISPLAY into a frame, a preview and a visualizer characteristic
    DISPLAY carried three meanings, preview, commit and visualizer columns,
    and the firmware picked one by its current mode while the app picked what
    to send by its own view of the mode. The two views are not shared and
    drift under confirmation lag, physical buttons and reconnects. When they
    drifted, column heights streamed for the visualizer were committed as a
    Display bitmap and written to NVS: reproducible on a device by starting
    the visualizer and reconnecting.
    Each write now says what it is by the characteristic it lands on.
    DISPLAY_FRAME (READ, WRITE, NOTIFY) is the committed frame: a write
    commits in any mode, persists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
    [main.rs]
2026-09-06 check firmware formatting in ci
    The tree was one collapsed call away from fmt-clean, and nothing kept it
    so: the only firmware job runs the host tests. This fixes that one line
    in led.rs and adds a formatting check, which costs seconds and turns a
    reformatting slip into a red check instead of a diff for the next person
    to untangle.
    [led.rs]
2026-09-06 document BLE protocol v3
    The characteristic table gains DISPLAY_FRAME, DISPLAY_PREVIEW and
    VISUALIZER and loses DISPLAY, listed in creation order, which is what ATT
    handles follow, with the preview stream first. The same-value MODE write
    is a no-op, and the preview/commit section describes durability by
    characteristic rather than by handshake state.
    The paragraph under the table says what happens to each kind of v2
    client. One that rediscovers rejects the device on the missing UUID. One
    that trusts its cache writes its frames into the volatile preview, and
    every other handle it cached moved as well: its timer read lands on a
    characteristic with no READ and its pomodoro commands land on
    DISP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
2026-09-06 keep every mode's state alive across a mode switch
    The main loop built a fresh handler on every mode change, so leaving a mode
    threw its state away. Long-pressing white during a pomodoro to glance at the
    dice and coming back found the timer Idle with the elapsed time gone, and the
    pet reset to its starting hunger and mood. Nothing was persisted either, so a
    power cycle did the same.
    A Runtime now owns all three handlers for the life of the process and the mode
    only selects which one draws. Every handler ticks each pass, so a pomodoro
    keeps counting and the pet keeps getting hungry while another mode is on the
    matrix; entering a mode shows what it has been doing rather than a fresh start.
    B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
    [main.rs]
2026-09-06 give the standalone a seam its logic can be tested through
    Nothing in this crate could run off the device. Every module reached an
    ESP-IDF type, the ESP-IDF dependencies were unconditional, and build.rs asked
    embuild for a sysenv that only exists for the ESP32 target, so a host build
    failed before it compiled a line. The arithmetic behind the two modes with any
    arithmetic in them went untested.
    The ESP-IDF crates move behind `cfg(target_os = "espidf")` and build.rs only
    reads the sysenv for that target, which is what the companion firmware already
    does. lib.rs exposes the modules that need nothing from the device:
    - mode_values holds the numbering persisted in NVS and the order the white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
    [main.rs]
2026-09-06 run the standalone through firmware ci
    Firmware CI only ever entered companion/firmware, so the standalone was built
    by nothing until a tag reached release.yml. It now runs as a matrix over both,
    and each leg checks formatting and runs the host tests its lib.rs exposes.
    Two things had to be true first. The toolchain was a floating `nightly`, which
    the same CI step resolves fresh on every run and which may or may not carry
    rustfmt; it takes the pin and the components the companion already documented.
    And the tree was not fmt-clean, so `cargo fmt` runs over it here rather than
    leaving the first red build to whoever pushes next.
    [led.rs, main.rs]
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2026-09-06 keep the matrix from taking the device down with it
    Every SPI write in the display driver unwrapped, so one failed row panicked
    the firmware: a pet, a pomodoro and a mode were lost to a transfer that the
    next tick would have redrawn anyway. Failures are now logged and the frame is
    abandoned, stopping at the first bad row because UART logging blocks the main
    loop.
    show also takes a fixed-size frame. Its old signature accepted any slice and
    answered a short one with a hardcoded smiley, an answer no caller ever needed
    and none could now ask for.
    [led.rs]
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
